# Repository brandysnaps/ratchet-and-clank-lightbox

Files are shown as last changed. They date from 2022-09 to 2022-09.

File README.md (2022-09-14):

# Ratchet & Clank Lightbox

For my brother’s 21st birthday, I wanted to combine his love of Ratchet & Clank and adding coloured lights to his room to make a custom 3D printed lightbox for his wall.

Head on over to the project [website](https://brandysnaps.github.io/ratchet-and-clank-lightbox) for more details :sparkles:

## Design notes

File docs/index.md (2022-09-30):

---
cover-img: ["assets/images/cover-img-1.jpg", "assets/images/cover-img-2.jpg", "assets/images/cover-img-3.jpg", "assets/images/cover-img-4.jpg"]
layout: home
show-avatar: false
subtitle: Building a 3D printed Ratchet & Clank lightbox for my brother's 21st birthday.
title: Ratchet & Clank Lightbox
---

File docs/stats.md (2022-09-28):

---
layout: page
title: Project stats
---

## Wakatime



### Code Time

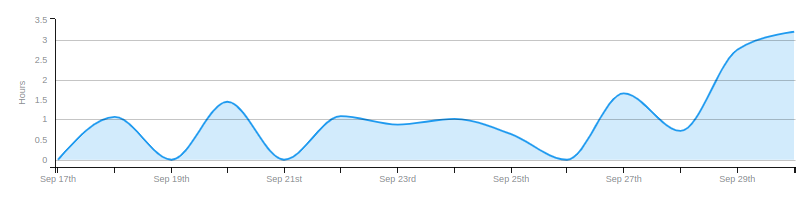
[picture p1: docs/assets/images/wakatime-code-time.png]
WakaTime code time


### Languages

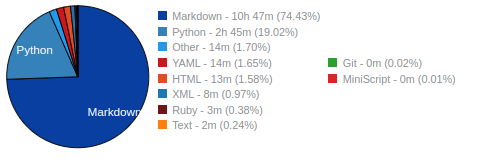
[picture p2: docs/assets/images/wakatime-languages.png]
WakaTime languages


### Files

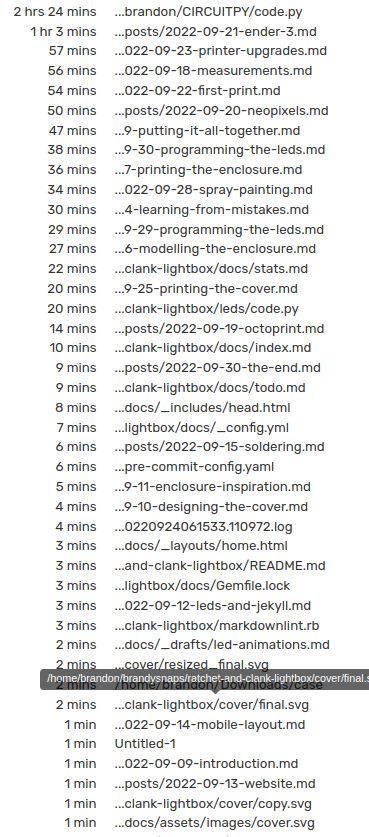
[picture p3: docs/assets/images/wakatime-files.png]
WakaTime files


## 3D Printing Time

| Print | Time (HH:mm) |
| --- | --- |
| Cover | 07:28 |
| Enclosure | 11:24 |
| Raspberry Pi Pico case | 00:39 |
| **Total** | **19:31** |

## Filament Used

| Print | Filament used (m) |
| --- | --- |
| Cover | 13.18 |
| Enclosure | 29.01 |
| Raspberry Pi Pico case | 1.36 |
| **Total** | **43.55** |

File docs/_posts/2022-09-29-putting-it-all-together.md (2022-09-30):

---
cover-img: assets/images/a-team.jpg
date: 2022-09-29 06:00:00 +1300
layout: post
readtime: true
title: "Putting it all together"
---

Now that the printed parts are dry, I have a few things to do:

* Fit test
* Soldering the connector wires to the LED strip
* Fitting the LED strip inside the enclosure
* Fitting the diffustion paper in the enclosure

## Fit Test

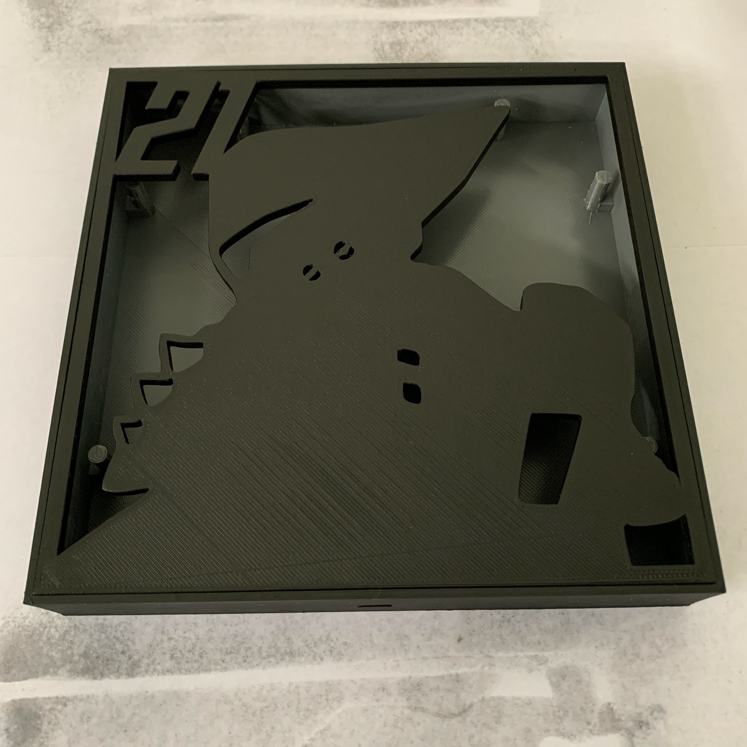
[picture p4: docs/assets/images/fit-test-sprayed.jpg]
Fit test


I am so happy with how the project is looking. The spray paint did not add any noticeable thickness to the pieces so the fit is still not that snug. Looks like I will have to use Blu-Tack or similar to hold the cover in place. That is not a big deal as long as it's not visible. Blu-Tack means the cover can be easily removed at any time to allow access to the internals.

## Soldering the Connector Wires

I soldered some female connector wires on the input end of the LED strip to allow it to easily be attached to the Pico. I soldered some male connector wires on the output end of the LED strip to allow it to easily be extended in the future:

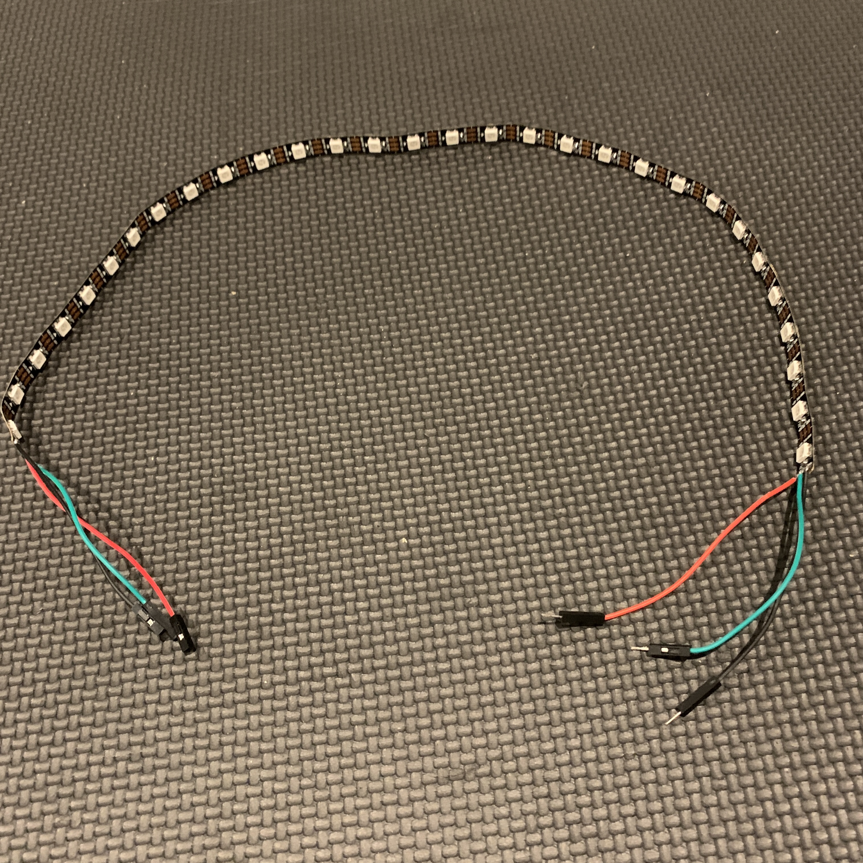
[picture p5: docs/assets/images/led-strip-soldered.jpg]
LED strip soldered


## Fitting the LED Strip

I carefully bent the LED strip at the locations of corners inside the enclosure. I did a quick fit test to make sure there were the correct number of LEDs per side and that the LED strip supports would not get in the way of the LEDs. Once I was happy, I removed the backing from strip to reveal the adhesive and stuck it to the walls of the enclosure. This is the result:

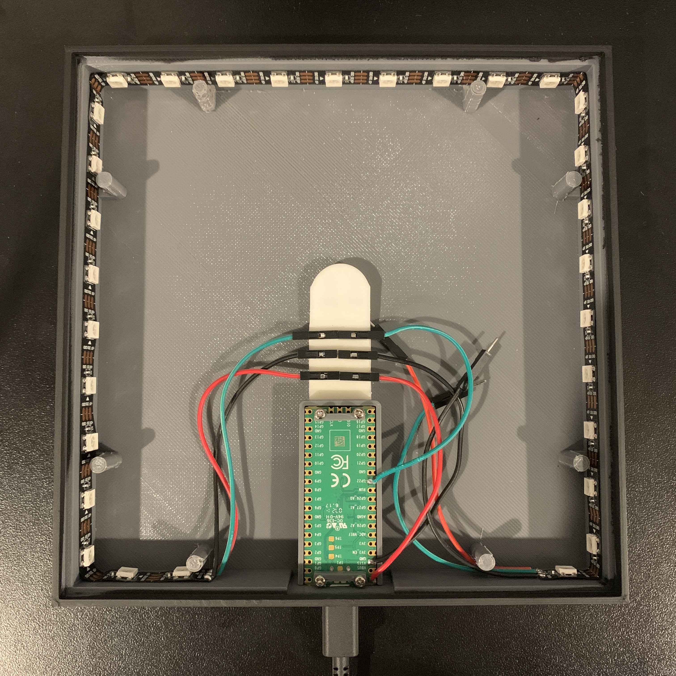
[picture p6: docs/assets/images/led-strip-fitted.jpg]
LED strip fitted


It's looking very clean if I do say so myself.

## Diffusion Paper and Cover

I cut a piece of diffusion paper (lol just joking - it's normal A4 printer paper) to size, and placed it on the inner lip of the enclosure. Next, I placed the cover on top. Are you ready for it? This is the first time everything has been put together and pretty much exactly represents the completed project:

...

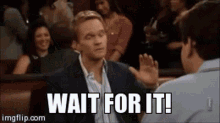
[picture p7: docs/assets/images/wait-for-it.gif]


...

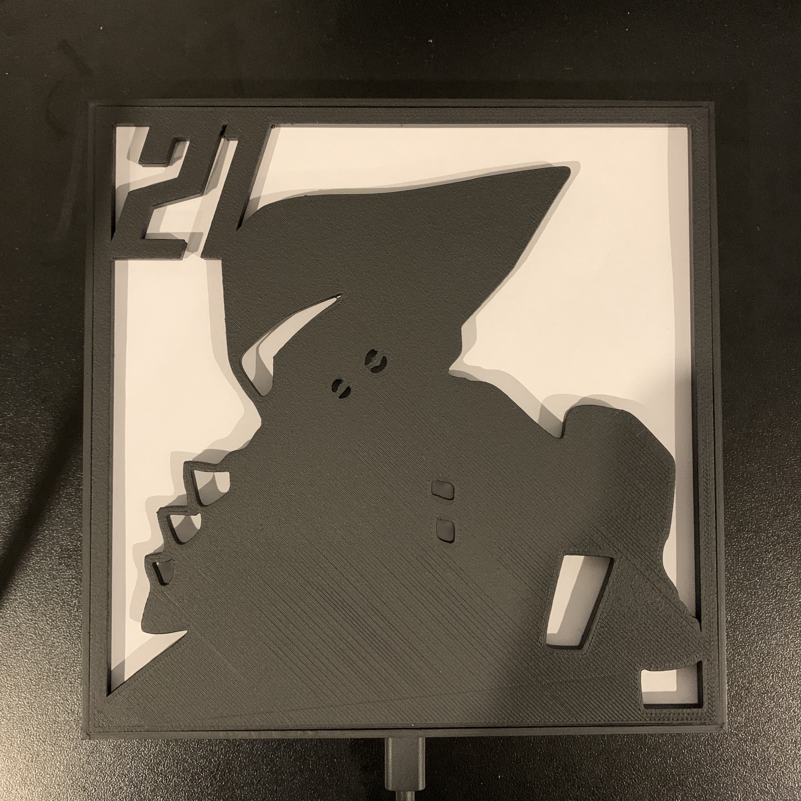
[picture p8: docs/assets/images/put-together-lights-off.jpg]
Fully assembled


Beautiful.

I wrote some basic code to get a rainbow displaying on the LED strip to see what it looks like diffusing through the paper:

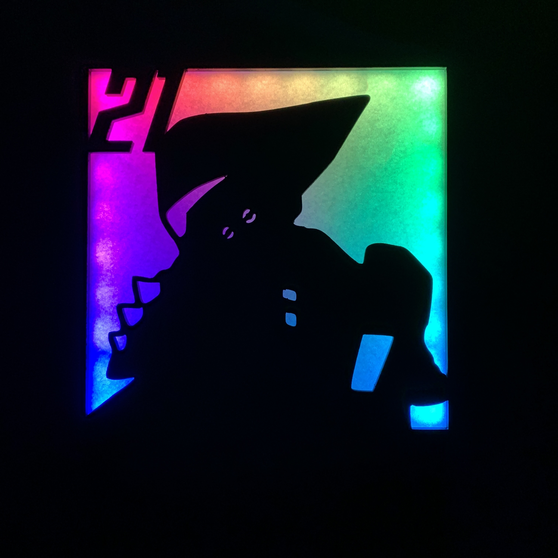
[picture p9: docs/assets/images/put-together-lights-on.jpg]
Rainbow


I'm a little disappointed with how much you can see the LEDs through the paper but there is not much I can do about that at this stage. I really need more vertical clearance between the LEDS and the paper but that would require another 3D print. I could look at printing the diffuser with some white filament in the future but don't have any on hand.

I'm sure this won't bother anyone else but I find that I tend to get critical of everything when I have been working on a project for so long 😩. Oh well, I am 93% happy.

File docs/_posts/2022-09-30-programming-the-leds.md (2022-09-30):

---
cover-img: assets/images/matrix.gif
date: 2022-09-30 06:00:00 +1300
layout: post
readtime: true
tags: [LEDs, Pico, Raspberry Pi]
title: "Programming the LED strip"
---

Now that everything is sitting where it should be, one of the last things to do is pre-program the Pico with some LED animations based on the pink and blue colour scheme my brother likes:

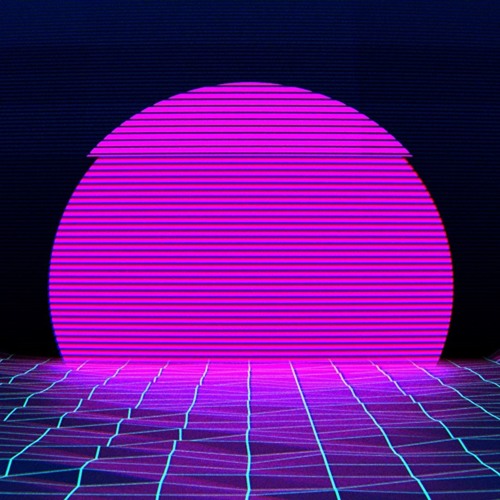
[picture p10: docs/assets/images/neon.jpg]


I am using the `adafruit_led_animation` library for the colours and animations. The first step is to include the required classes from the library, like so:

```python
import board
import neopixel
from adafruit_led_animation.sequence import AnimationSequence
from adafruit_led_animation.animation.chase import Chase
from adafruit_led_animation.animation.colorcycle import ColorCycle
from adafruit_led_animation.animation.comet import Comet
from adafruit_led_animation.animation.pulse import Pulse
from adafruit_led_animation.animation.solid import Solid
from adafruit_led_animation.animation.sparkle import Sparkle
from adafruit_led_animation.animation.SparklePulse import SparklePulse
```

The next thing to do is check is if the library provides out-of-the-box colours matching what I have in mind. I found that the `CYAN` colour from `adafruit_led_animation.color` is exactly what I want. Unfortunately, the `PINK`, `MAGENTA` and `PURPLE` colours do not match what I had in mind. Instead, I did some Googling and found a pink I liked. These are the "blue" and "pink" RGB values:

<table>
  <tr>
    <td>
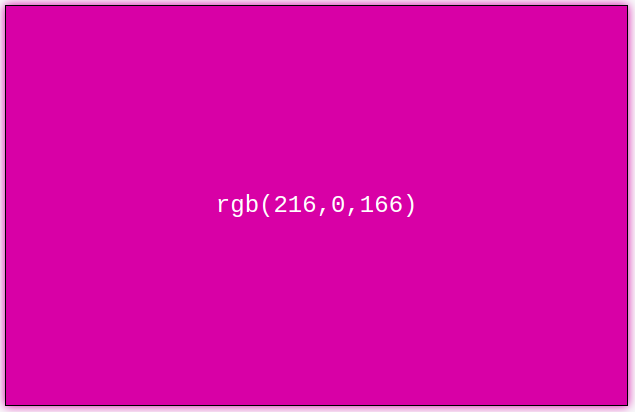
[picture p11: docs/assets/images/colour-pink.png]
      
    </td>
    <td>
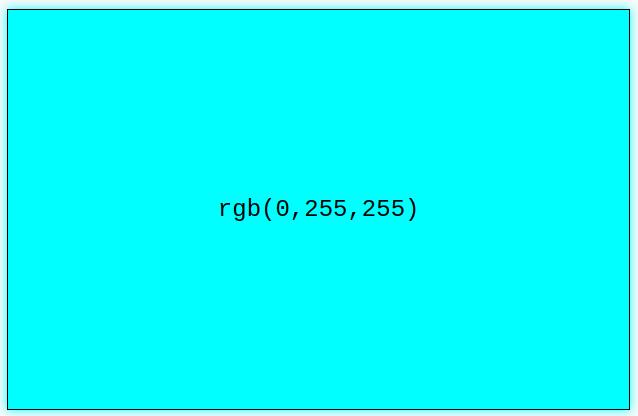
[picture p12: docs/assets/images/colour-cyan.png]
      
    </td>
  </tr>
</table>

I set up these colours in the code:

```python
from adafruit_led_animation.color import CYAN

# Define colors here
COLOR_1 = CYAN
COLOR_2 = (216, 0, 166)  # Pink
```

Next, I went through each of the animation types in the [CircuitPython LED Animations][circuitpython-led-animations] document and selected the options I thought looked the best. For example:

```python
chase_1 = Chase(pixels, speed=0.1, color=COLOR_2, size=2, spacing=3)
color_cycle = ColorCycle(pixels, speed=5.0, colors=[COLOR_1, COLOR_2])
comet_1 = Comet(pixels, speed=0.075, color=COLOR_2, bounce=False)
pulse_1 = Pulse(pixels, speed=0.1, color=COLOR_1, period=5)
```

Lastly, I had to configure an `AnimationSequence` to cycle through all of the animations I set up. I decided to let the animations be chosen at random, and for each animation to play for 60 seconds:

```python
animations = AnimationSequence(
    chase_1,
    chase_2,
    color_cycle,
    comet_1,
    comet_2,
    pulse_1,
    pulse_2,
    solid_1,
    solid_2,
    sparkle_1,
    sparkle_2,
    sparkle_pulse_1,
    sparkle_pulse_2,
    advance_interval=60,
    auto_clear=True,
    random_order=True,
)
```

Here is the complete code for reference:

```python
# Pre-programmed LED strip animations for Ratchet & Clank lightbox
#
# API documentation: https://docs.circuitpython.org/projects/led-animation/en/latest/
#
# Author: Brandon Farrell
# 29/09/2022

import board
import neopixel
from adafruit_led_animation.sequence import AnimationSequence
from adafruit_led_animation.animation.chase import Chase
from adafruit_led_animation.animation.colorcycle import ColorCycle
from adafruit_led_animation.animation.comet import Comet
from adafruit_led_animation.animation.pulse import Pulse
from adafruit_led_animation.animation.solid import Solid
from adafruit_led_animation.animation.sparkle import Sparkle
from adafruit_led_animation.animation.SparklePulse import SparklePulse
from adafruit_led_animation.color import CYAN

# Define colors here
COLOR_1 = CYAN
COLOR_2 = (216, 0, 166)  # Pink

# LED attributes
pixel_brightness = 0.5
pixel_num = 30
pixel_pin = board.GP22

pixels = neopixel.NeoPixel(
    pixel_pin, pixel_num, brightness=pixel_brightness, auto_write=False
)

# Animations
chase_1 = Chase(pixels, speed=0.1, color=COLOR_2, size=2, spacing=3)
chase_2 = Chase(pixels, speed=0.1, color=COLOR_1, size=2, spacing=3)
color_cycle = ColorCycle(pixels, speed=5.0, colors=[COLOR_1, COLOR_2])
comet_1 = Comet(pixels, speed=0.075, color=COLOR_2, bounce=False)
comet_2 = Comet(pixels, speed=0.075, color=COLOR_1, bounce=False)
pulse_1 = Pulse(pixels, speed=0.1, color=COLOR_1, period=5)
pulse_2 = Pulse(pixels, speed=0.1, color=COLOR_2, period=5)
solid_1 = Solid(pixels, color=COLOR_1)
solid_2 = Solid(pixels, color=COLOR_2)
sparkle_1 = Sparkle(pixels, speed=0.05, color=COLOR_1)
sparkle_2 = Sparkle(pixels, speed=0.05, color=COLOR_2)
sparkle_pulse_1 = SparklePulse(
    pixels, speed=0.05, period=5, min_intensity=0, max_intensity=1.0, color=COLOR_1
)
sparkle_pulse_2 = SparklePulse(
    pixels, speed=0.05, period=5, min_intensity=0, max_intensity=1.0, color=COLOR_2
)

animations = AnimationSequence(
    chase_1,
    chase_2,
    color_cycle,
    comet_1,
    comet_2,
    pulse_1,
    pulse_2,
    solid_1,
    solid_2,
    sparkle_1,
    sparkle_2,
    sparkle_pulse_1,
    sparkle_pulse_2,
    advance_interval=60,
    auto_clear=True,
    random_order=True,
)

while True:
    animations.animate()

```

Once the complete code had been successfully uploaded to the Pico, I disconnected it and started packaging it in the box I will give my brother...

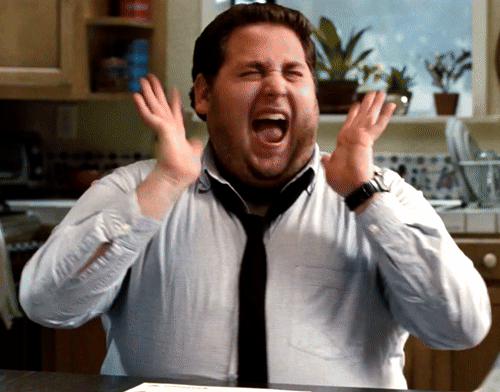
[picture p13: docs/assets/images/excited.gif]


## QR Code

It's a small thing but excited me nonetheless. I created a QR code linking to the website. I will make the site live tonight.

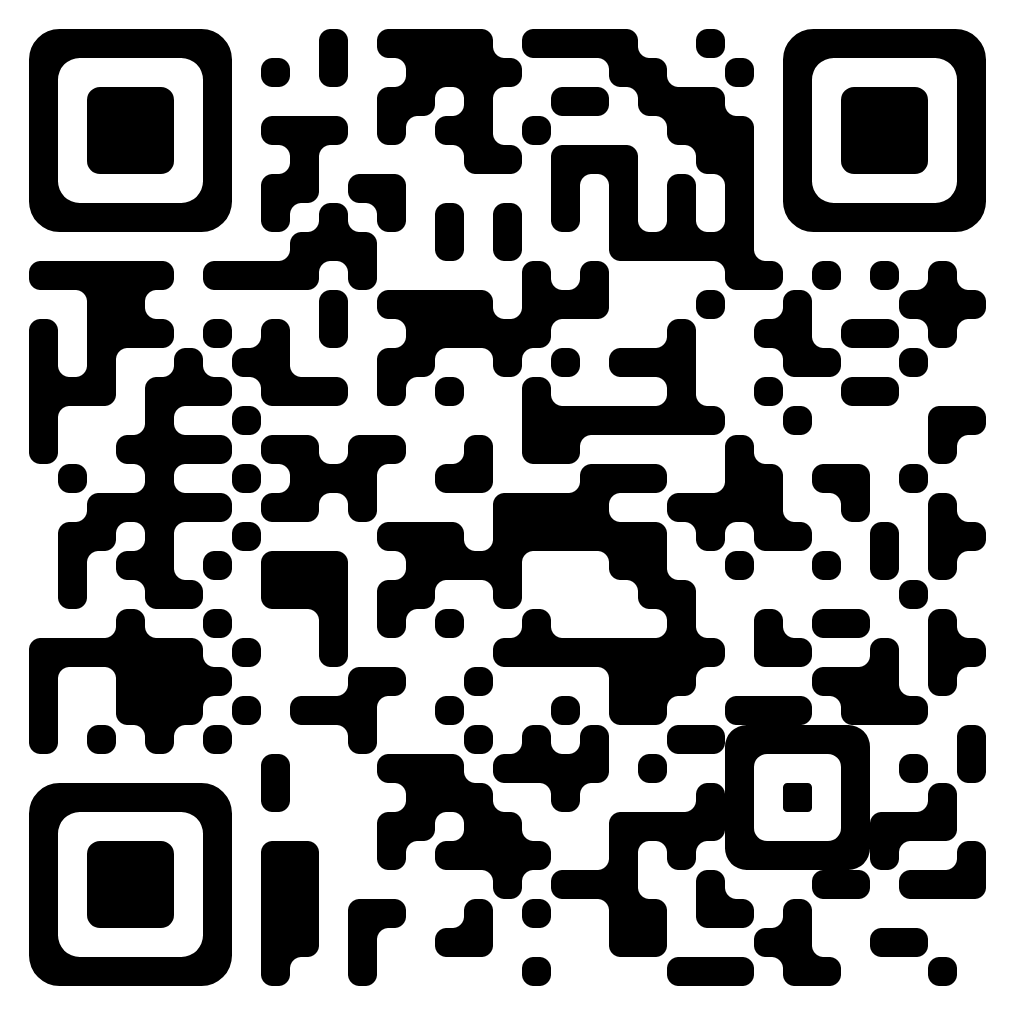
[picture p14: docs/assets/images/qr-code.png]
QR code


[circuitpython-led-animations]: https://learn.adafruit.com/circuitpython-led-animations

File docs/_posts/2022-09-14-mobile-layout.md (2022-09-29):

---
cover-img: assets/images/micropython-pico.jpg
thumbnail-img: assets/images/micropython-pico-thumbnail.jpg
date: 2022-09-14 06:00:00 +1200
layout: post
readtime: true
tags: [Raspberry Pi, Pico]
title: "Mobile layout & Raspberry Pi Pico"
---

I started today by trying to tackle the small mobile layout issues I found last night. In the evening, I started reading about getting my Raspberry Pi Pico set up.

## Mobile Layout Issues

Having a look at the mobile layout for the website reveals a couple of issues:

Mobile issues

Firstly, the main site heading is covered by the centered avatar. There is also a random navigation button up the top right that has nothing in it.

I decided to shorten the main site title to `R&C Lightbox` as there are other references to the full name elsewhere. That addresses the first issue but unfortunately I was not able to find a fast and good solution to the second problem. My options would be to update the beautiful-jekyll theme with custom logic for mobile, or create an issue on the project itself asking the author to fix it. I am short on time so will leave it as is for now. If I do end up adding any other page types to the site, this will not be an issue as the navigation button will no longer be empty.

## Raspberry Pi Pico

For a long time, I have wanted to make my way through the [Get Started with MicroPython on Raspberry Pi Pico book from Hackspace][micropython-pico]:

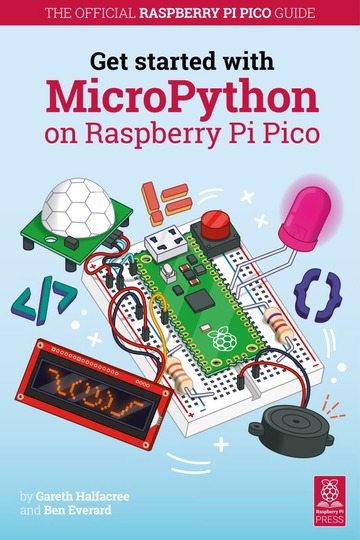
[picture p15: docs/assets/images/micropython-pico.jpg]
Get Started with MicroPython on Raspberry Pi Pico book


Like a few other things I have wanted to do for a long time, this project has given me the motivation to finally start.

I read about the different parts of the Pico and how to solder the header pins to it safely. This is what I will do first.

[micropython-pico]: https://hackspace.raspberrypi.com/books/micropython-pico

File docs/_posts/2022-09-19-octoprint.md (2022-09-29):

---
cover-img: assets/images/octoprint.png
date: 2022-09-19 06:00:00 +1200
layout: post
readtime: true
tags: [3D printing, Octoprint]
thumbnail-img: "assets/images/octoprint-thumbnail.png"
title: Octoprint
---

I spent a little time today getting [Octoprint][octoprint] installed and running on an old Raspberry Pi model B I had lying around. Octoprint will let me monitor the printing process remotely and create timelapses of any prints I make. I would like to include a timelapse of printing this project as I think it would be a nice touch.

The camera module I have was suprisinly easy to set up. I will have to figure out how to mount the camera to properly view the print bed, but that will come later (once I've actually built the printer 🤦‍♂️).

The one concern I have it that my Rasperry Pi model B is old and may struggle to run Octoprint. The website recommends model 3 onwards.

[octoprint]: https://octoprint.org/

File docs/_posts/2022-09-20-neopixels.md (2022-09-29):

---
cover-img: "assets/images/neopixels.gif"
date: 2022-09-20 06:00:00 +1200
layout: post
readtime: true
tags: [LEDs, Raspberry Pi, Pico]
title: "NeoPixels"
---

My goal for today is to be able to control a strip of NeoPixel LEDs using the Raspberry Pi Pico.

I found the [NeoPixel LEDs][adafruit] post on Adafruit's website that seems to be exactly what I want to do.

The first thing I did was cut my LED strip to the correct size (30 LEDs) and grabbed some wires to let me control the strip to the header pins on the Pico.

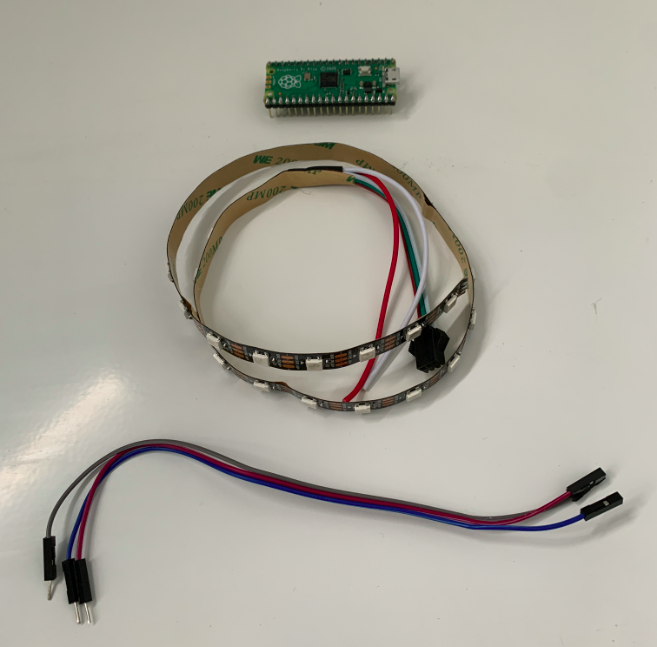
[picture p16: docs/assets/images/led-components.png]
Components


## Wiring the NeoPixel LED Strip

I wired everything up as follows:

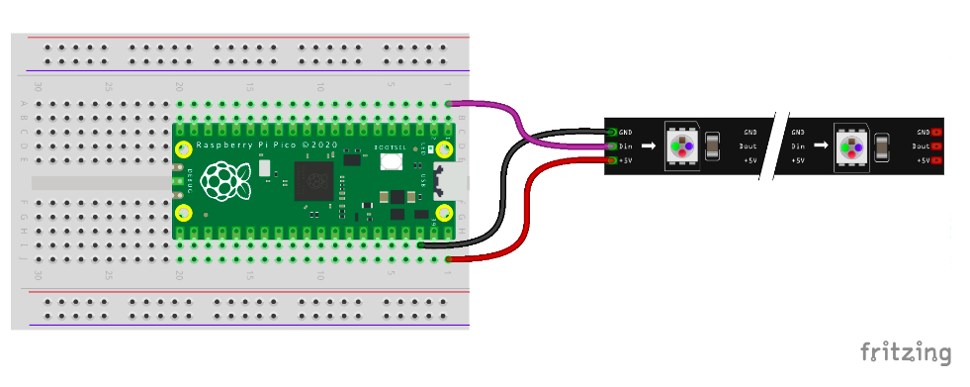
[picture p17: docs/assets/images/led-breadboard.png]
Wiring diagram


## Installing the Adafruit CircuitPython NeoPixel Library

Once that was done, I downloaded CircuitPython for the Pico. This was a UF2 file. I held down the **BOOTSEL** button on the Pico before plugging it into my laptop. This brought it up as a drive labelled `RPI-RP2`. I dragged the UF2 file to the new drive. After a couple of seconds, it reappeared with the name `CIRCUITPY`. Apparently this means CircuitPython is successfully installed 🎉.

The next step was to download the necessary library to use the NeoPixels. I copied the `neopixel.mpy` file to the `lib` directory as instructed by the docs. I then replaced the contents of the `code.py` file with the following:

```python
# SPDX-FileCopyrightText: 2021 Kattni Rembor for Adafruit Industries
#
# SPDX-License-Identifier: MIT

"""
NeoPixel example for Pico. Turns the NeoPixels red.

REQUIRED HARDWARE:
* RGB NeoPixel LEDs connected to pin GP0.
"""
import board
import neopixel

# Update this to match the number of NeoPixel LEDs connected to your board.
num_pixels = 30

pixels = neopixel.NeoPixel(board.GP0, num_pixels)
pixels.brightness = 0.5

while True:
    pixels.fill((255, 0, 0))
```

I wasn't really expecting anything to happen but after saving the file, to my surprise:

My eyes!

Even at 50%, these things are bright.

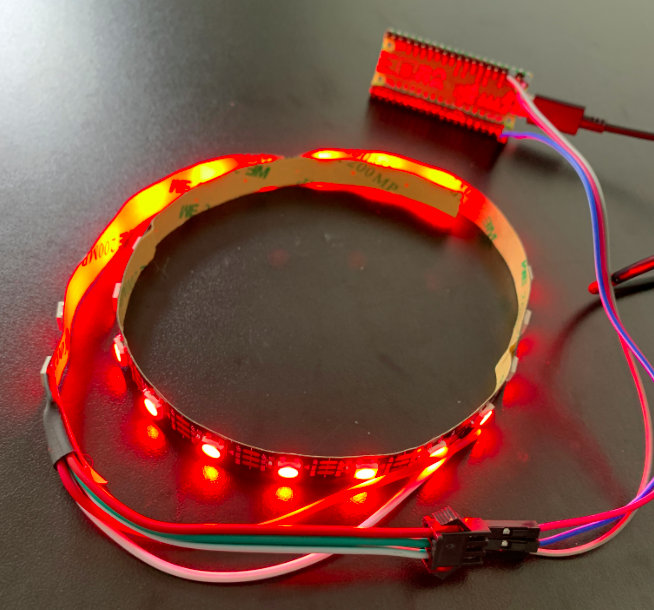
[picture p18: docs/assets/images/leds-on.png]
Let there be light


Reference: [Adafruit CircuitPython NeoPixel][circuit-python-neopixel]

## Animations

The next thing I want to look at is creating some animations based around the blue and pink colour scheme my brother likes.

This looks like a good place to start: [CircuitPython LED Animations][animations]

[adafruit]: https://learn.adafruit.com/getting-started-with-raspberry-pi-pico-circuitpython/neopixel-leds
[circuit-python-neopixel]: https://github.com/adafruit/Adafruit_CircuitPython_NeoPixel
[animations]: https://learn.adafruit.com/circuitpython-led-animations

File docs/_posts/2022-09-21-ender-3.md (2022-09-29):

---
cover-img: assets/images/desk.jpg
date: 2022-09-21 06:00:00 +1200
layout: post
readtime: true
thumbnail-img: "assets/images/ender-3-thumbnail.jpg"
tags: [3D printing]
title: "Building the Ender 3"
---

I have been both looking forward to and dreading this day for a long time. I bought the Creality Ender 3 3D printer about 6 months ago but have still not built it. Life got busy and I was convinced something would go wrong, so I lost the motivation I had before to buy and build my own printer.

But... I cannot give my brother a 3D printed lightbox without having a functioning 3D printer 😅.

So here it goes...

I open the box the printer comes in to see what I am dealing with. First glance makes me feel like this won't be so bad:

Box contents

I started unpacking and surprise! There is another layer:

Box contents (part 2)

...

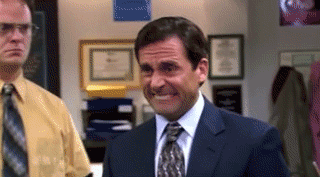
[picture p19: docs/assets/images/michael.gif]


I unpacked everything and laied it on the ground to get a better idea of what I was dealing with:

Printer components

I should have really unpacked those bags on the left because there were many, many parts in there. Following the single-page instruction manual was not too difficult and I supplemented that with a YouTube video. After about an hour, I ended up here:

Partly built

This is apparently the most important part to get right and makes up the core of the printer. If the vertical and horizontal members are all square and secure, the printer should print with decent results.

After a couple more hours, and a long break in the middle (who has spare time with young kids running around? 😂), it was done:

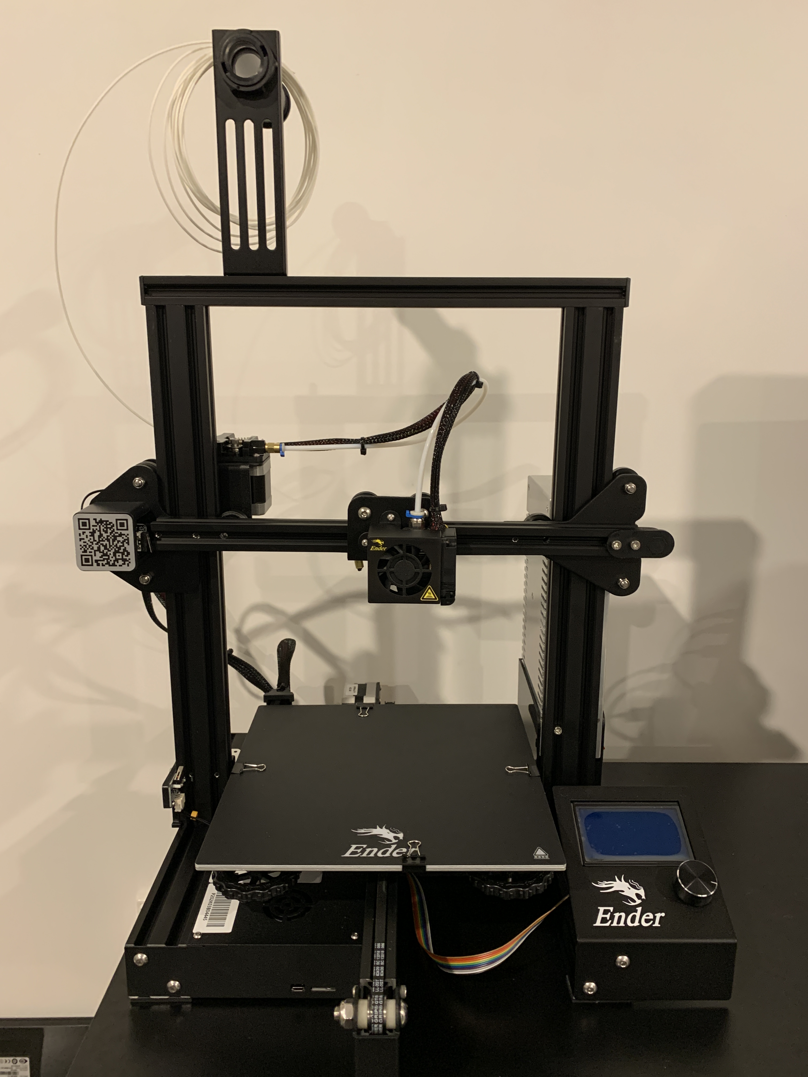
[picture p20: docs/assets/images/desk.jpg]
Finished printer


I really wanted to include a video here but I will have to figure out how to do that later. Here is my first print!

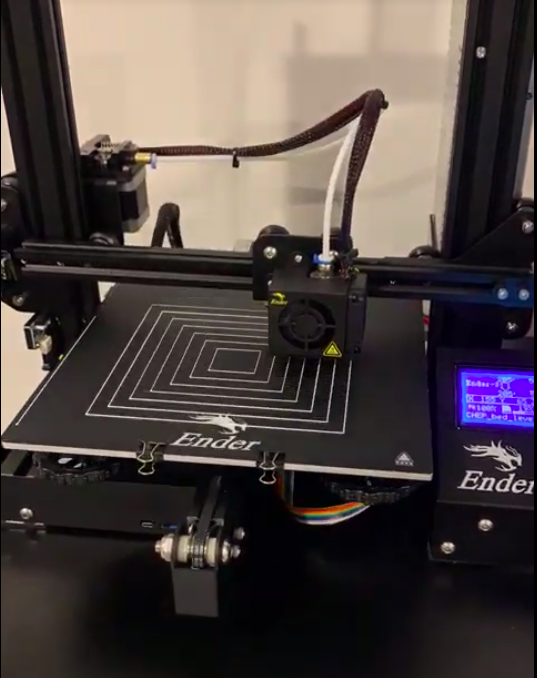
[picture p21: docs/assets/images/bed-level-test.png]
Bed level test


This was a simple bed level test, to make sure I had the print bed nice and level relative to the nozzle.

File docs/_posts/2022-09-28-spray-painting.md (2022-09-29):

---
cover-img: assets/images/spiderman-spray-paint.jpg
date: 2022-09-28 06:00:00 +1200
layout: post
readtime: true
title: "Spray painting"
---

I was happy with the spray paint test I did the other day but obviously when it comes to doing the real thing, the pressure is on!

From what I have read about post-processing 3D prints, it is a good idea to suspend the print in the air from a piece of string or similar. You then apply even strokes of paint while rotating the print. I used some thin string and tied it to the cover and enclosure.

The spray paint I am using is Flat Black Rust-oleum:

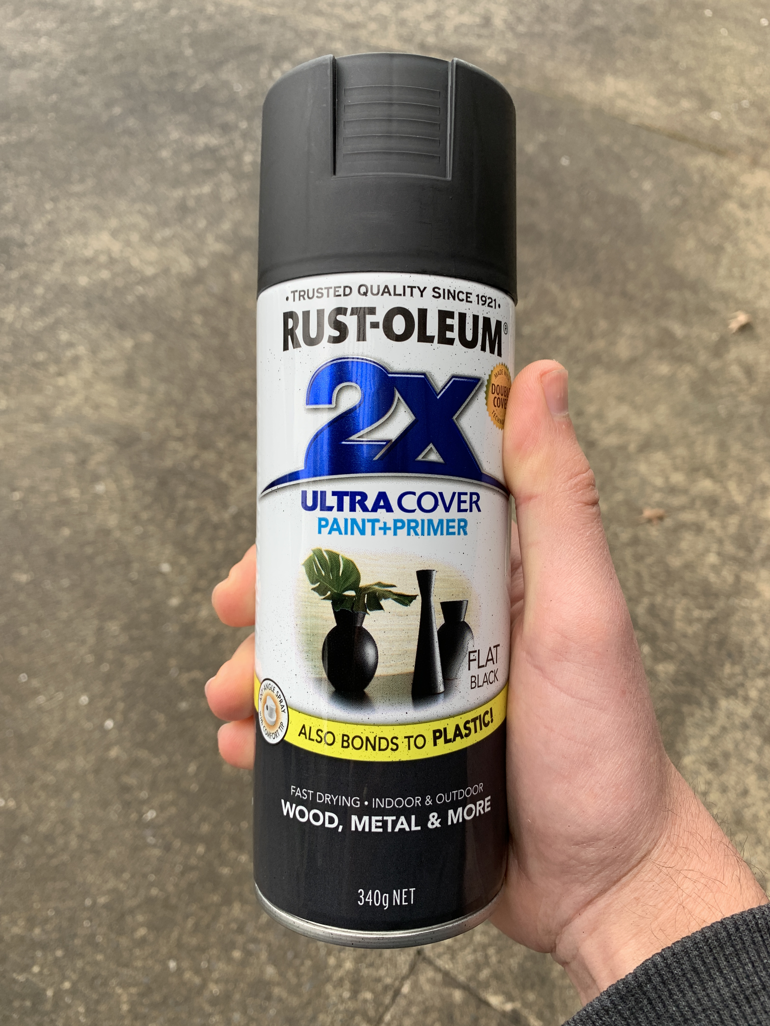
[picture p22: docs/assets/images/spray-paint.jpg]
Rust-oleum


I started with the enclosure and tried to apply nice even strokes. I could tell pretty quickly that hanging the piece vertically was not the best idea. A drip-like pattern was appearing on the back of the enclosure as gravity caused the paint to move. From then on, I decided to just lay the pieces flat and spray on top of some paper. When dry, I would turn the piece over and spray the other side. I did two coats of paint per side:

Cover sprayed

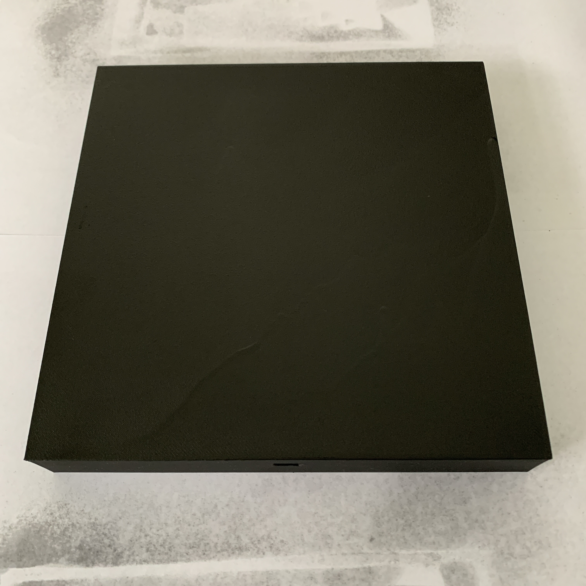
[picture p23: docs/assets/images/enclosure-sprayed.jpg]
Enclosure sprayed


I will leave both pieces to dry for 24 hours before trying to fit them together.

## Soldering the Wires to the Pico

I initially wanted to avoid soldering anything to the Pico itself because that is semi-permanent. My preference was to use wires with female headers on one end and plug them into the header pins on the Pico. Unfortunately, that increases the height of the Pico a lot, and I would have to make the enclosure a lot thicker to accommodate for this. My goal was to make the project as thin as possible so I decided to solder the three required wires directly to the Pico. As you can see, this adds no height and is far easier to fit into a thin space:

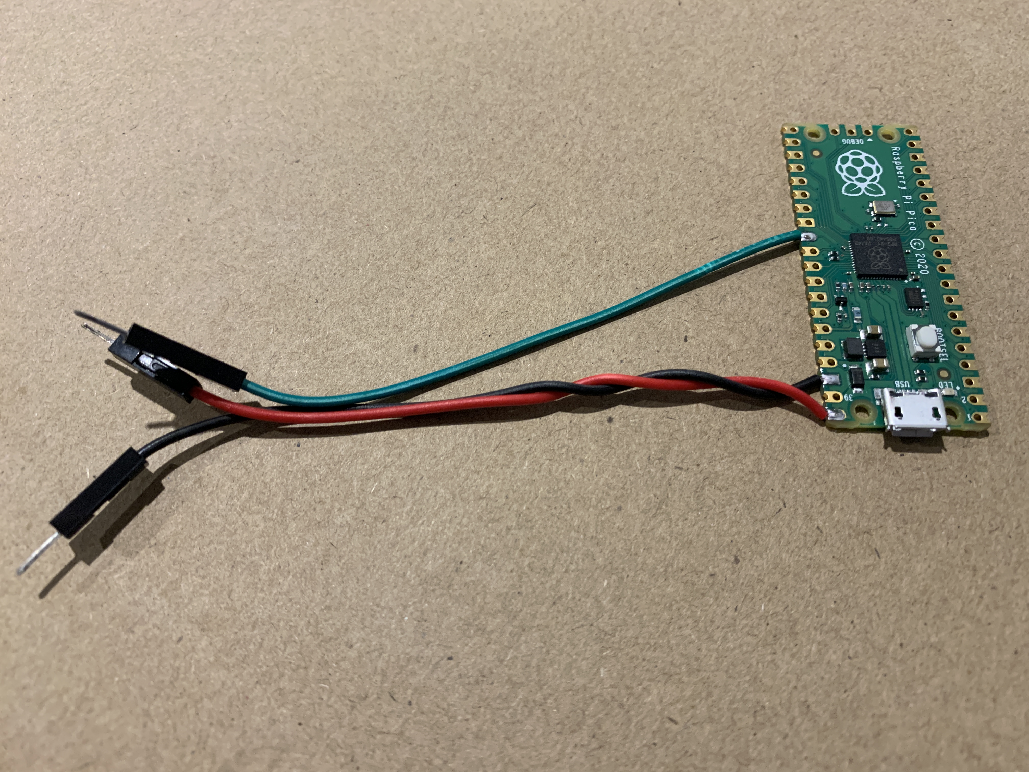
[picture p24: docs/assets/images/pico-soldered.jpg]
Pico with wires soldered


The data wire (green) was originally set to the bottom right pin shown in the picture above (GP0):

{% highlight python %}
pixels = neopixel.NeoPixel(board.GP0, num_pixels, auto_write=False)
{% endhighlight %}

If I kept using the bottom right pin, I would have had to bend it over/under the Pico to be on the same side as the red (VBUS) and black (GND) wires. Instead, I decided to use a GPIO pin on the left side of the board, as close to the other wires as possible. GP22 seemed like a good candidate so I changed the wiring and updated the code to the following:

{% highlight python %}
pixels = neopixel.NeoPixel(board.GP22, num_pixels, auto_write=False)
{% endhighlight %}

The LED strip turned on as expected 💡.

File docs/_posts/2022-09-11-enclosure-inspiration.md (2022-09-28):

---
cover-img: assets/images/lightbox-inspiration.jpg
date: 2022-09-11 00:00:00 +1200
layout: post
readtime: true
tags: [3D printing, Tinkercad]
title: "Initial thoughts on the enclosure"
---
Today was all about getting a better idea of what the enclosure will look like. I have an idea of what I want it to look like in my head but when it comes to putting that into millimeter measurements, that's a bit more challenging.

I've decided to go with a 200 mm x 200 mm square. I think 30 mm think will work but I won't know until I am actually holding something in my hand.

Dimensions

One of the other things that is bothering me is how I am going to attach the image to the rest of the encolsure. Possible options include glue, bolts and friction. I want something that is not permanent so my brother can switch out the front picture if he wants. This pretty much rules out glue. I have the least confience in friction because it relies on 3D printing with very small tolerances so the pieces fit together nicely. Bolts seemed to be the best option but I don't know how to make this work without losing some space on the image for bolt holes.

Image mounting options

The next challenge is how to mount the Raspberry Pi Pico inside the enclosre. One of the features I've decided on is to be able to plug a power cable directly into the enclosure so the Pico needs to be mounted in such a way that it's power port is accessible and does not move when something is plugged into it.

This is what I have in mind to start with:

<table>
  <tr>
    <td>
      Not found
    </td>
    <td>
      Not found
    </td>
  </tr>
</table>

It also needs to be easily removable and detachable from the electronic wiring so it can have new software flashed to it.

I stumbled onto some nice case designs for a Pico that I think I can adapt to work well:

| **Upper case** | Upper case
| --- | --- |
| **Lower case** |Lower case|

Reference:[Slim modular Raspberry Pi Pico Case][pico-cases]

The idea is keep the mounting holes in place but stretch the **Upper case** design to the dimensions I want (200 mm x 200 mm). This should leave me with mounting holes for a Pico at one of the edges with the power port easily accessible.

The Pico is then sandwiched between the upper and lower cases to hold it in place with some bolts.

This is what the case looks like with a Pico inserted and no modifications:

Pico

[pico-cases]: https://www.thingiverse.com/thing:4808999

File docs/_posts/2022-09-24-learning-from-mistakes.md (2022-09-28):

---
cover-img: "assets/images/this-is-fine.jpg"
date: 2022-09-24 06:00:00 +1200
layout: post
readtime: true
tags: [3D printing, Octoprint, Cura]
title: "What have I gotten myself into?"
---

They say that you learn from your mistakes. I learned a lot today.

I wanted to print this cable chain to tidy up the wiring at the back of the printer:

Cable chain

There are a couple of models in this [Thingiverse][thingiverse] thing that need many copies of it printed. I thought it would be a good idea to print as many of them in a single print batch as possible, so I do not have to set up the same print 19 times. I imported the model into Cura and used the multiply function to get the required number of pieces:

Cura layout

This looked great so I started the print and went on my merry way. The print was supposed to take around 9 hours. I checked back in after around an hour and already suspected something was wrong. The quality on each of the pieces just wasn't what I expected it to be.

After around 5 hours, things were looking very bad. Some of the pieces were very messy and looked like they had clouds of fine spaghetti plastic on their top. I decided to cancel the print. The pieces would not have been usable and I didn't want to waste even more filament.

I thought about this for a while and realised what the likely problem is. The printer was printing a single layer at a time for all pieces on the print bed. It would print a layer for the first piece, then a layer for the second, and so on. Once all pieces had their first layer printed, it would return to do the second layer on the first piece. The print head was moving so much between all the pieces, leading to the stringing I was seeing. I wonderered if there was a way to print each piece in its entirety before moving on to the next one. I would still be printing one piece at a time but would not need to do all the set up if I were printing a single piece on the print bed at a time.

Turns out there is a setting in Cura for that: Special Modes -> Print Sequence -> One at a Time.

The "downside" with that setting is that you cannot print as many models on the bed, because the print head needs enough clearance when moving between pieces so nothing gets bumped around. I found that I was able to fit 6 of the smaller model on the bed at a time.

I kicked off the next print and immediately saw a problem. For some reason, the first layer was a complete mess. The extruder did not seem to working properly at all. Basically, it looked like the printer stopped working altogether...



Took me a while to figure out the cause of this one. I noticed an issue at the top of the stepper motor that feeds filament into the bowden tube. There were specs of filament on it and the filament itself had notches taken out of it from the teeth on the stepper motor. This was almost certainly caused by all of the extrusion and retraction of the filament from the disaster of the previous print. I checked the 'Maximum Retraction Count' setting in Cura and it was set to 100. That is WAY too high and it's no surprise I wrecked the filament. I reduced that setting to 5, started a new print and things were back to normal.

I need a drink

The plan for tomorrow is to print the cover of my brother's present. Hopefully it's a more successful day...

[thingiverse]: https://www.thingiverse.com/thing:3769941

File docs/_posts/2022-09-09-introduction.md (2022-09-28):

---
cover-img: assets/images/introduction.jpg
date: 2022-09-09 00:00:00 +1200
layout: post
readtime: true
title: "Introduction"
---
For my brother's 21st birthday, I wanted to combine his love of Ratchet & Clank and adding coloured lights to his room to make a custom lightbox for his wall.

He is a big fan of this pink and blue neon style:



He was recently showing me something on his computer and I spotted a profile picture he had made for himself:

Profile picture

My goal is to build a physical representation of this profile picture using a 3D printer, Rasperry Pi Pico and some RGB LEDs.

I found this on Thingiverse with has a similar feel for what I want to create:

Hexaleafs

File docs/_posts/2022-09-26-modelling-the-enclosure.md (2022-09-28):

---
cover-img: assets/images/enclosure-top-right.png
date: 2022-09-26 06:00:00 +1200
layout: post
readtime: true
tags: [3D printing, Cura, Pico, Raspberry Pi, Tinkercad]
title: "Enclosure modelling & spray paint test"
---

It took me a long time to get something I was happy with:

Enclosure model (top-right)
Enclosure model (top)

I imported the STL of the cover to make sure everything fits. It would be a disaster to print the enclosure, only to discover my measurements were wrong.

Enclosure with cover (top-right)
Enclosure with cover (top)

I decided to keep the case for the Pico separate from the enclosure so that it can be swapped out for the ESP32 development board which is currently on its way from China. The reason I want to use the ESP32 is so that the LED strip can be controlled with [WLED][wled]. WLED offers the following advantages:

* Over 100 special effects
* Mobile app for remote control
* Alexa voice control (including dimming and color)
* Nightlight function (gradually dims down)

Unfortunately, I cannot do this with the non-wireless Pico I have so he will have to make do with my pre-programmed lighting animations for now 😂.

The plan is to use a couple 3M Velcro strips to hold the Pico (and later ESP32) board in place. It should be strong enough to allow plugging the power cable in from the outside without it moving around.

I did a quick slice of the STL file to get an idea of the print time. More than 17 hours… oh my. I referred back to the [Hexaleaf Thingiverse][hexaleaf] page and saw the author printed at a layer height of 0.2 mm. I did the cover at 0.12 mm and was very happy with the quality. However, re-slicing in Cura with a layer height of 0.2 mm means a print time of just over 12 hours. This seems more reasonable so is what I have decided to go with:

Enclosure sliced

## Spray Paint Test

I grabbed a piece of orange scrap from one of my previous failed prints. I used orange because I figure if black spray paint can hide orange, it can certainly hide grey. I hung the piece up outside, gave the can a good shake and tried to do nice even strokes with the spray until I had completely covered the face. I left it to dry for around an hour before taking it inside to look at the results. I am blown away with the difference! Not just the colour but the finish to the surface as well.

There was nothing wrong per se with the finish before but you could clearly see the print lines:

Unsprayed scrap

Compared to the sprayed black side, the surface is clearly smoother and has a nice matte finish:

Sprayed scrap

I feel more confident taking the spray can to the cover now as long as I use the same technique as the test piece.

## Raspberry Pi Pico Case

I printed the case for the Raspberry Pi Pico that will sit inside the enclosure. I am happy with the result and glad to see the M2 8 mm screws I have work 😅. It is the first time I have really relied on the accuracy of my printer. If the screw holes were not printed at the correct size, the screws would not have worked.

Raspberry Pi Pico case

Tomorrow I will be printing the enclosure…

[hexaleaf]: https://www.thingiverse.com/thing:5154193
[wled]: https://kno.wled.ge/

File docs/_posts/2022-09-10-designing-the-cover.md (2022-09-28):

---
cover-img: assets/images/final_svg.png
date: 2022-09-10 00:00:00 +1200
layout: post
readtime: true
tags: [Gimp, Inkscape]
title: "Designing the cover"
---
The first task in my mind was to get the front image of the lightbox designed. From what I have read, the best way to get a clean image for 3D printing is to create a SVG formatted file that I can import into it Tinkercad to generate a STL file that the 3D printer can use.

This is the image I am taking inspiration from:

Profile picture

I want to be able to shine light through all of areas my brother has highlighted in pink, as well as the background behind Rathet.

After spending some on Google, I was able to find the original image. I wanted to make sure the orientation and details matched as closely to the above image as possible:

Original image

From here, I used Gimp to make the original set of image modifications.

## Gimp

### Crop

The first step was to crop the image and remove the background colour:

Sized image

### Highlight Details

I then highlighted the key areas I want light to come through:

Accents image

I decided to highlight the rings on Ratchet's mask as well to give the light somewhere else to come through. All of the detail of his suit will be lost in the final product so I want it to have as much detail as possible. It's a slight deviation from my bother's profile picture but hopefully he won't mind 😅.

### Add Outline

I want the spikes on Ratchet's shoulder to be illuminated, as well as the entire background. I needed to make sure there was a solid outline between the two so you can see the detail of the spikes:

Outlined image

## Remove Other Details

The last step was to end up with an image showing only the areas I want the light to come through:

Final image

This is a basic representation of what I hope the lightbox will look like. The green areas are where light will come through, the back is what will be 3D printed.

## Inkscape

The edges on the JPEG image above are not very clean and if I want to scale this image up, it will get blurry. I read about using a feature in Inkscape called "Bitmap tracing" to convert an image to the SVG format. SVG is a vector-based format at retains it's detail, no matter the scaling.

I wanted to add a border and "21" to the final image. This is what I ended up with:

Final SVG

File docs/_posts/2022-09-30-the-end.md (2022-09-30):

---
cover-img: assets/images/the-end.jpg
date: 2022-09-30 20:00:00 +1300
layout: post
readtime: true
title: "The end"
---

Well, there you have it. After 20 hours making this website, 20 hours printing and countless more hours thinking, designing and making, I have reached the end of the project. It's been a whirlwind trying to get this ready 😅.

Everything is packaged and now ready to present to my brother:

Packed box
Packed box

## To my brother

Happy 21st birthday! I cannot believe you have reached this milestone already. You are hands down, one of the best people I have the privilege of knowing and it's been such a joy watching you grow. I will forever cherish the memories I have of us bonding over Ratchet & Clank.

I hope this lightbox makes a fitting addition to your room. Given everything I have learned working on this project, if you want anything tweaked, let me know 😁.

Love you lots,

Brands

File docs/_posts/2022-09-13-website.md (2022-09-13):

---
# cover-img: "assets/images/website.png"
date: 2022-09-13 21:00:00 +1200
layout: post
readtime: true
tags: [Jekyll, Wacom]
thumbnail-img: "assets/images/website_thumbnail.png"
title: "Shiny new website!"
---
I spent WAY too much time today working on this website. I tend to do this. Going down rabbit holes of things that interest me rather than working on the highest priority task 😅.

## Beautiful Jekyll

Anyway, I found the [beautiful-jekyll][beautiful-jekyll] Jekyll theme and was inspired to use it for this site.

It's so beautiful

After figuring out how to make it work both locally and on GitHub, I went through the documentation to configure things just right.

I noticed right before going to bed that the mobile layout for the site is not rendering as I expected. Need to look into this tomorrow.

## Drawing Tablet

I have been wondering how to get the physical sketches I have of this project into this site. I considered just taking photos of everything, but I don't think these would look very nice considering a lot of them are just tiny pencil sketches on random bits of paper.

My brother recently bought himself a relatively cheap Wacom drawing tablet which he seems happy with. I did some research on the [One by Wacom][one-by-wacom] drawing tablet and it looks like it will work well for what I want to do. My brother confirmed this is the one he has too! It was fun asking him about it, knowing he has no idea what my plans are for his birthday 😁.

So, I took the plunge and am now the proud owner of one of these:

One by Wacom

## Sketchpad

I did some very quick digging and I should be able to use [Sketchpad][sketchpad] for creating all of my sketches.

[beautiful-jekyll]: https://github.com/daattali/beautiful-jekyll
[one-by-wacom]: https://estore.wacom.com/en-NZ/catalog/category/view/s/tablets/id/45/#one-by-wacom
[sketchpad]: https://sketch.io/sketchpad/

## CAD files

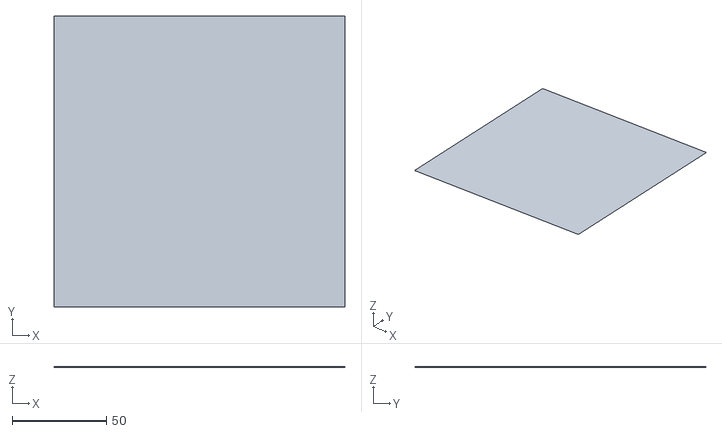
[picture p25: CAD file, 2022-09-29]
3d-printing/diffuser.stl
154.0 x 154.0 x 0.4

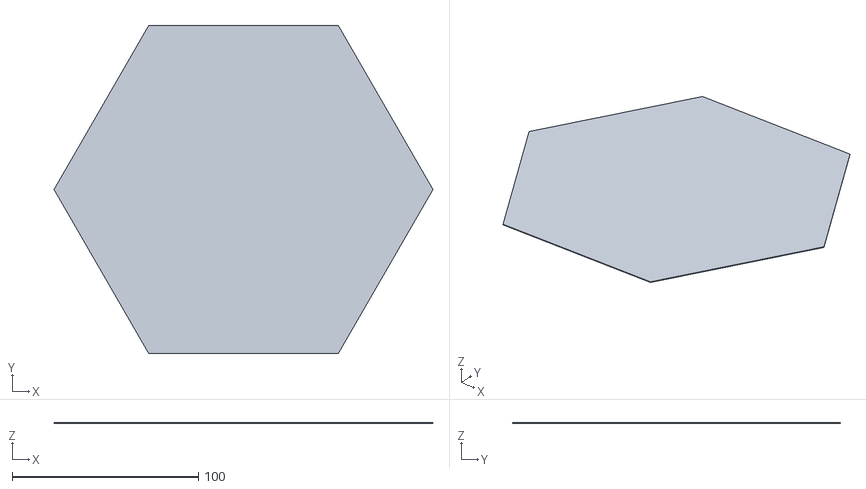
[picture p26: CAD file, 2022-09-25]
3d-printing/reference-models/Hexaleaf/Hexaleaf_Diffuser.stl
203.2 x 176.0 x 0.4

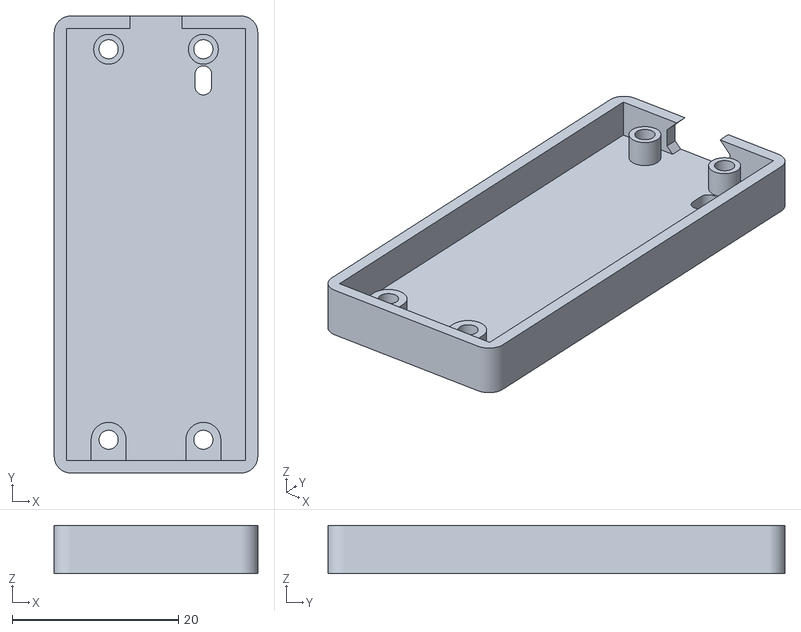
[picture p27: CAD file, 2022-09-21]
3d-printing/reference-models/Slim modular Raspberry Pi Pico Case/Case_Upper_No_Text.STL
24.5 x 55.0 x 5.80

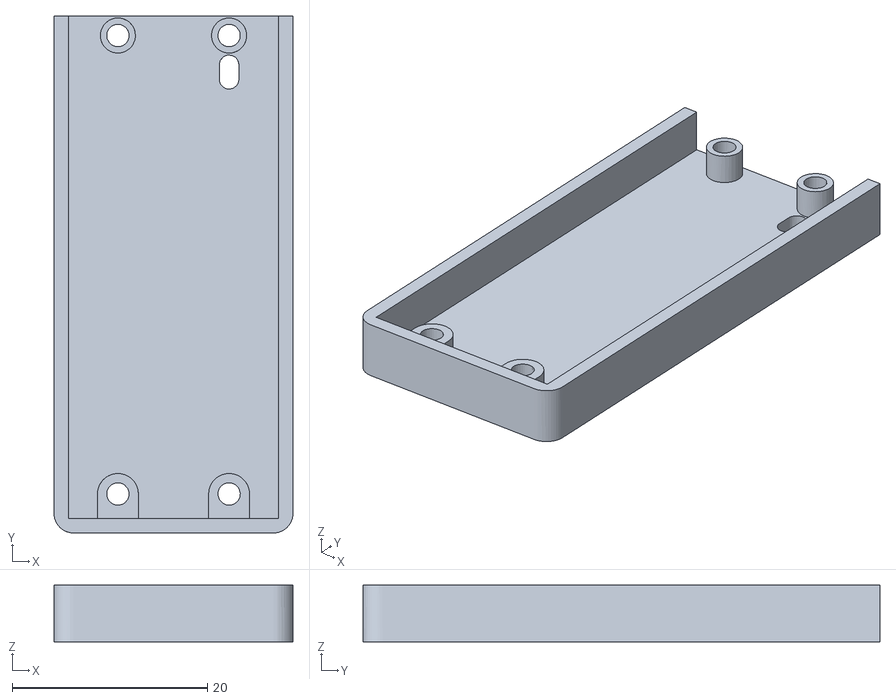
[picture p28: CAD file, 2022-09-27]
3d-printing/pico-case.stl
24.5 x 53.0 x 5.80

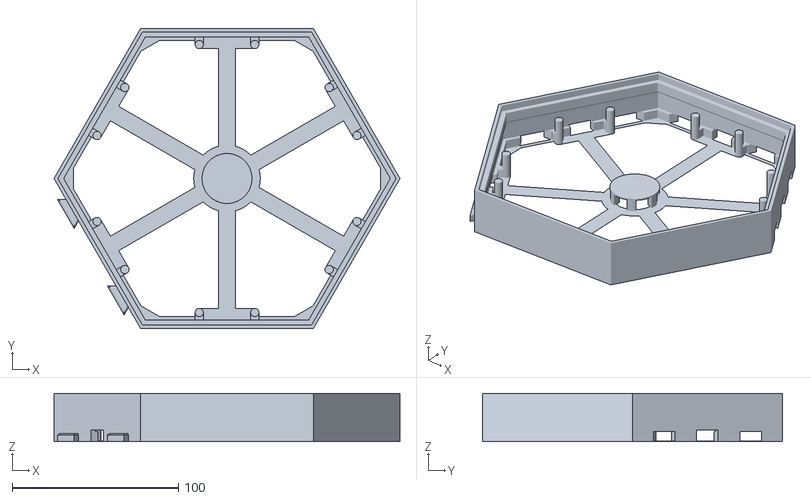
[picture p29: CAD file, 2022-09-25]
3d-printing/reference-models/Hexaleaf/IP65_Hexaleaf_m00fff.stl
207.8 x 180.0 x 29.0

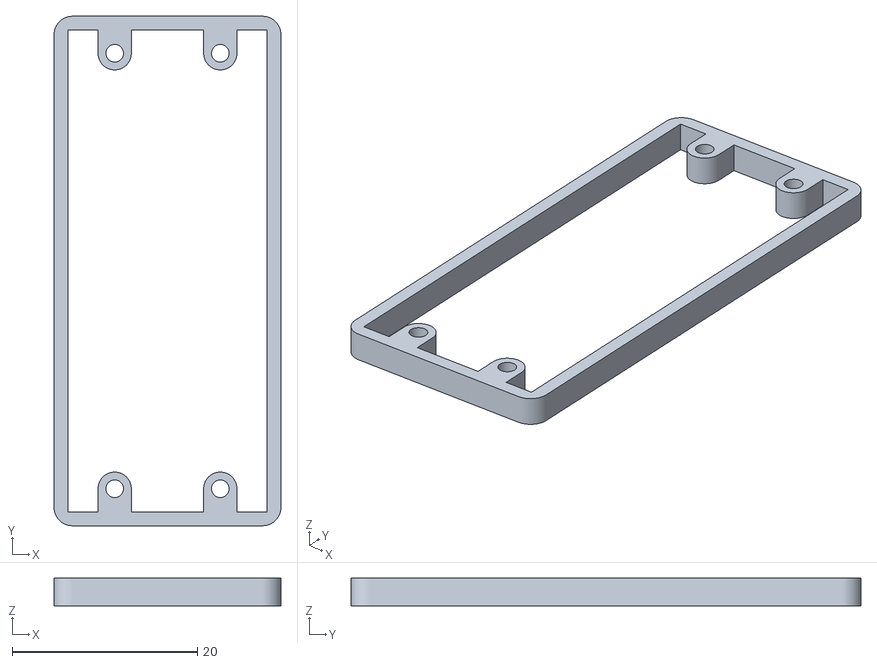
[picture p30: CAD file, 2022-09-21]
3d-printing/reference-models/Slim modular Raspberry Pi Pico Case/Case_Lower_Minimal.STL
24.5 x 55.0 x 3.00

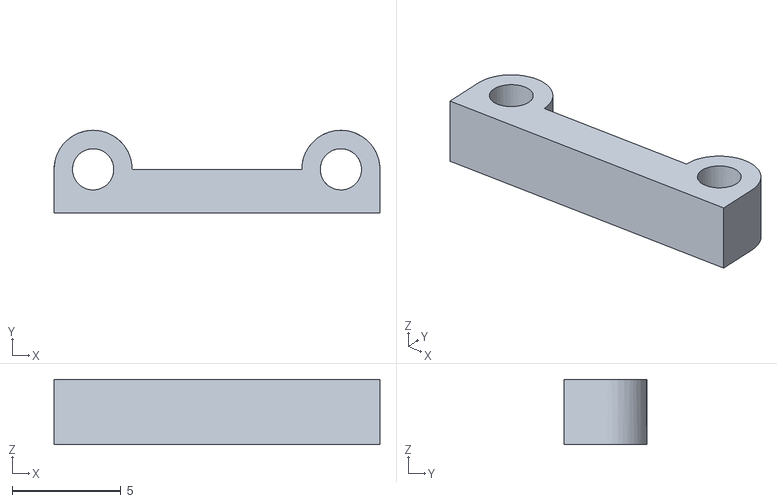
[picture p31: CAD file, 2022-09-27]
3d-printing/pico-holder.stl
15.0 x 3.80 x 3.00

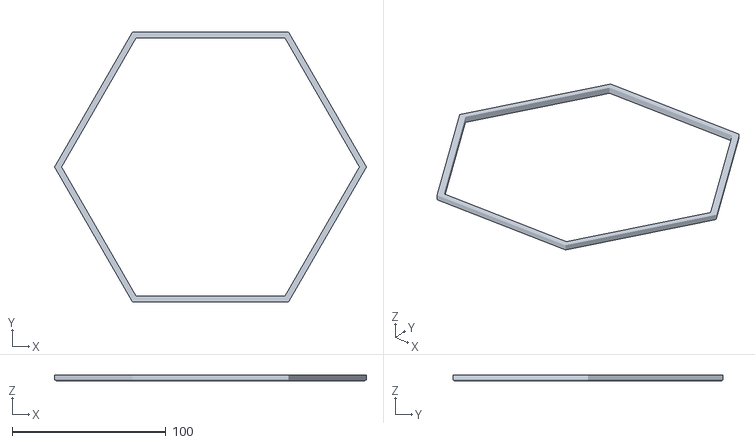
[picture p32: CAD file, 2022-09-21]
3d-printing/reference-models/Hexaleaf/Hexaleaf_Cover_Rim.stl
203.2 x 176.0 x 4.00

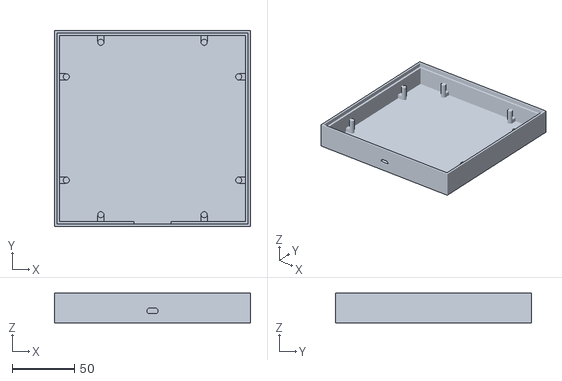
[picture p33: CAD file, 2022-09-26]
3d-printing/enclosure-with-port.stl
158.0 x 158.0 x 24.0

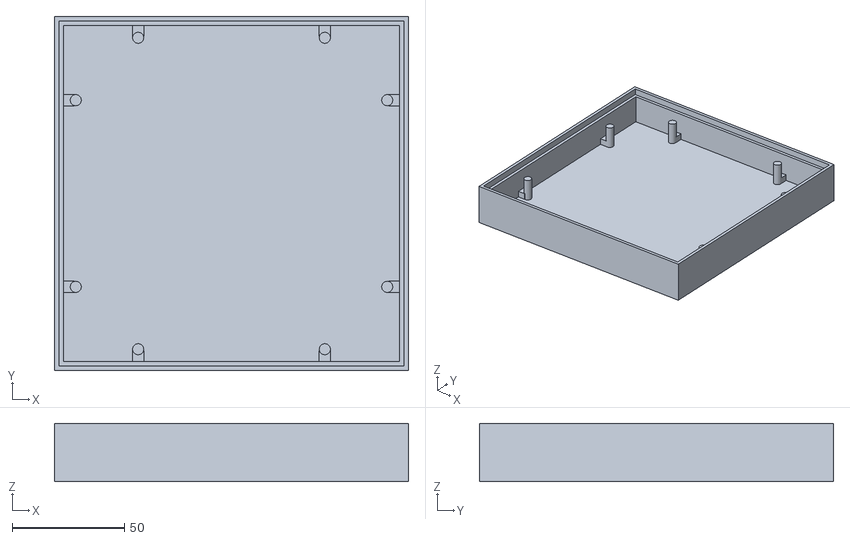
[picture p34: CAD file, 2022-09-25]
3d-printing/enclosure.stl
158.0 x 158.0 x 26.0

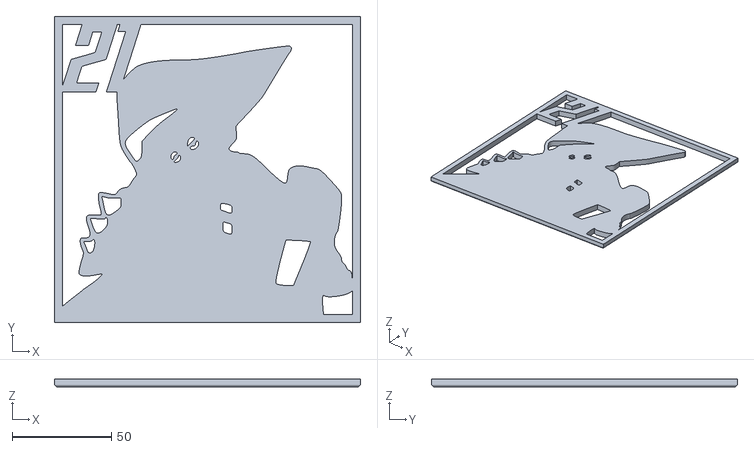
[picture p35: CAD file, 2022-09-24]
3d-printing/cover.stl
154.0 x 154.0 x 4.00

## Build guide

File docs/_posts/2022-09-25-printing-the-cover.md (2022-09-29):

---
cover-img: assets/images/cover-finished.jpg
date: 2022-09-25 07:00:00 +1200
layout: post
readtime: true
tags: [3D printing, Octoprint]
title: "Printing the cover"
---

I kicked the cover print off just after 7 am this morning. I got the slicing sorted in Cura first and then loaded the GCode into Octoprint. I was happy with the first layer and print adhesion:

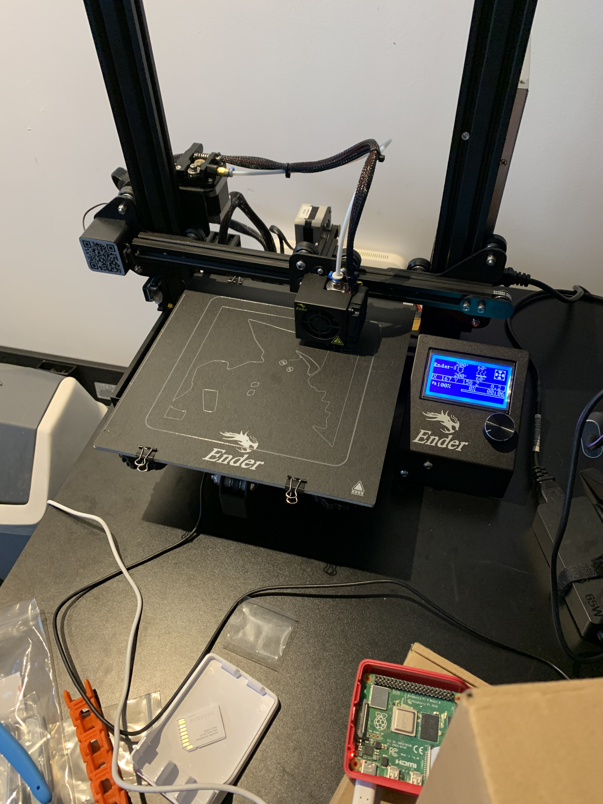
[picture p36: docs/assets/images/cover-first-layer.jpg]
First layer


I checked in on the print every now and then on my phone, to make sure nothing catastrophic was going on. After a few hours, you could start to see the infill being printed:

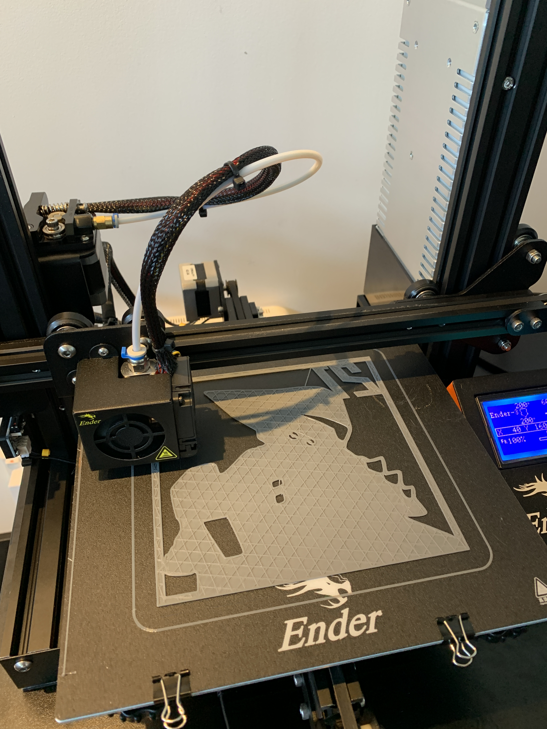
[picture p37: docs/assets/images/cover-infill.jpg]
Infill


I managed to grab a screenshot of the GCode viewer just before the last layer was finished:

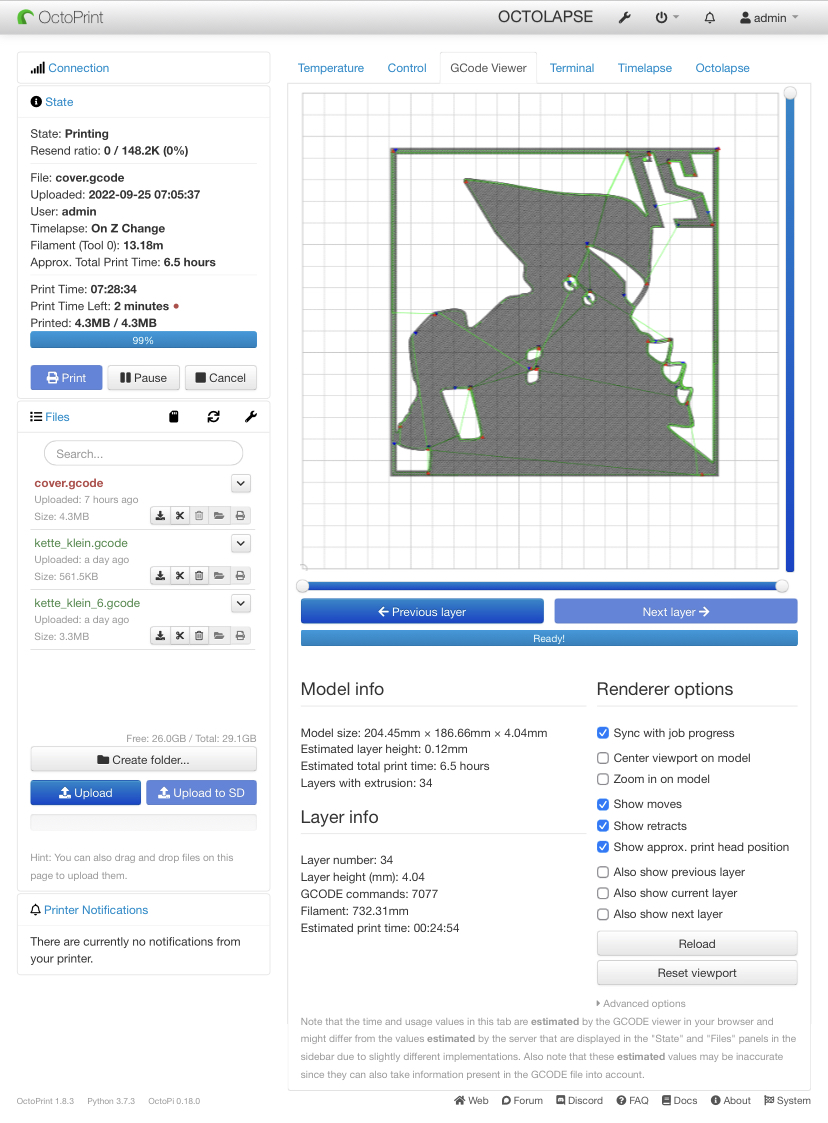
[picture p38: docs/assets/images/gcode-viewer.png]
Final layer


After 7 hours 28 minutes and 13.18 m of filament, the cover was done!

I waited a while to let the bed cool before very carefully removing the print. The print quality was extremely good and after removing some minor imperfections and stringing, this is the finished result:

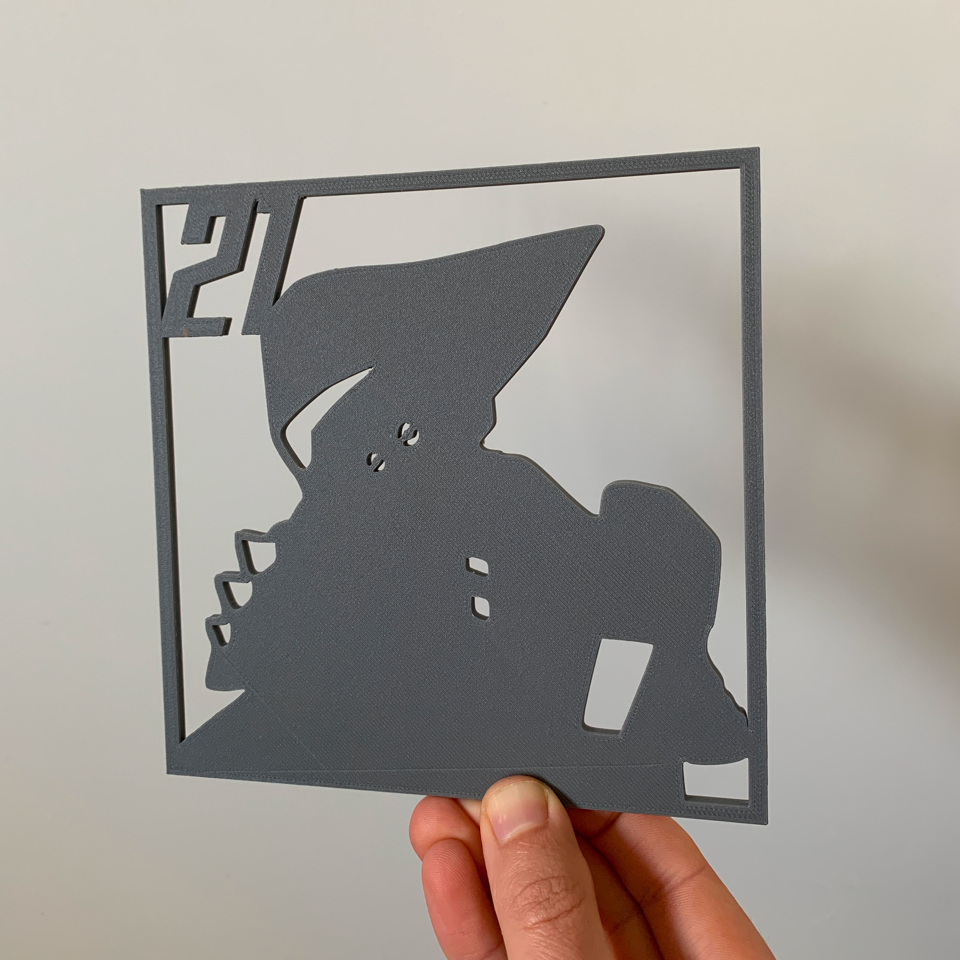
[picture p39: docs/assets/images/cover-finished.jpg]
Finished cover


I really want the finished gift to be black. I only have grey and orange filament at the moment so I went and bought some black spray paint from the local hardware store. Yet another thing to learn how to do.



Later in the evening, I spent more time trying to figure out the internals of the enclosure. There is a lot to think about and fit in so I sketched my thoughts out.

The inside of the enclosure will be laid out roughly as follows:

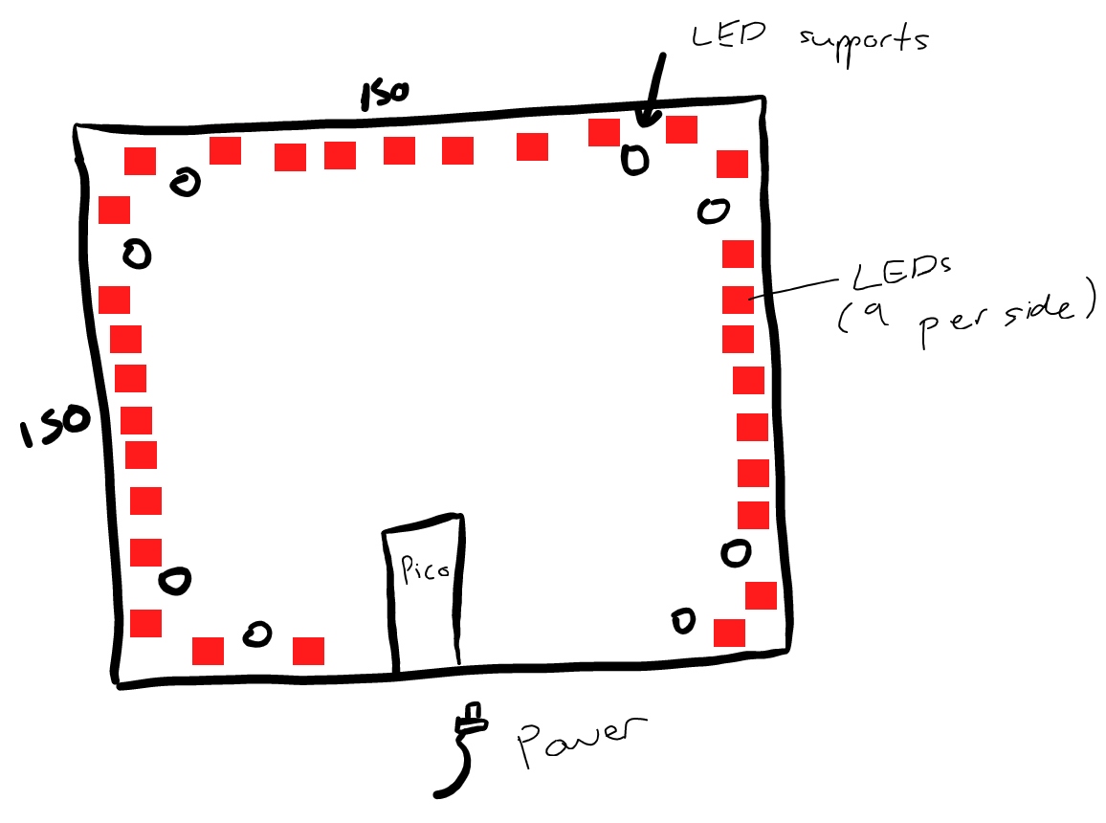
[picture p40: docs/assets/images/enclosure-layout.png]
Enclosure layout


The LED strip will be attached to the internal wall of the enclosure in a clockwise direction, starting at the Raspberry Pi Pico. There will be nine LEDs on each face except for the bottom, where there will only be three. This should not be a problem as the majority of the bottom portion of the cover is solid, meaning no light will come through anyway.

I have included two cylindrical LED strip supports on each side, similar to the Hexaleaf design:

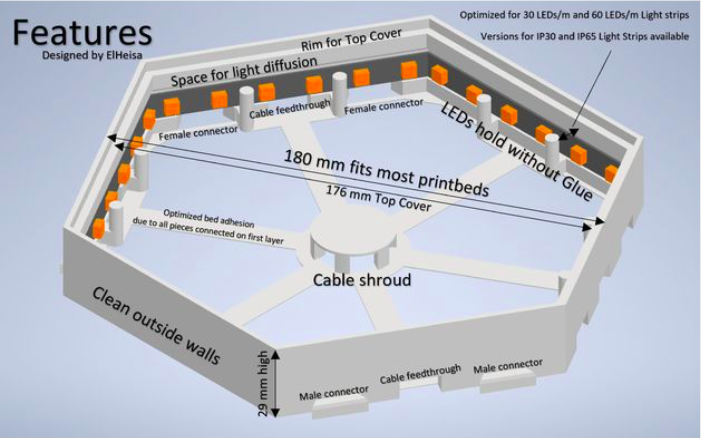
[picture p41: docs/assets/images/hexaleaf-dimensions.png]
Hexaleaf design


Cross-section where there is an LED strip support:

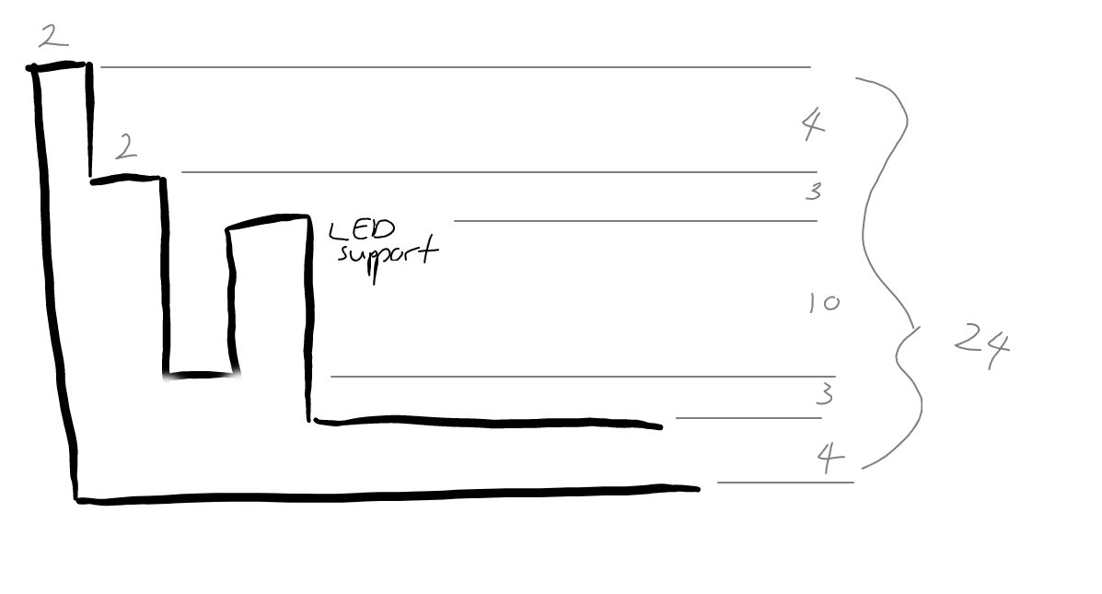
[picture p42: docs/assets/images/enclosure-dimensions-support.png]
Enclosure cross-section w/ support


Cross-section where there is no LED strip support:

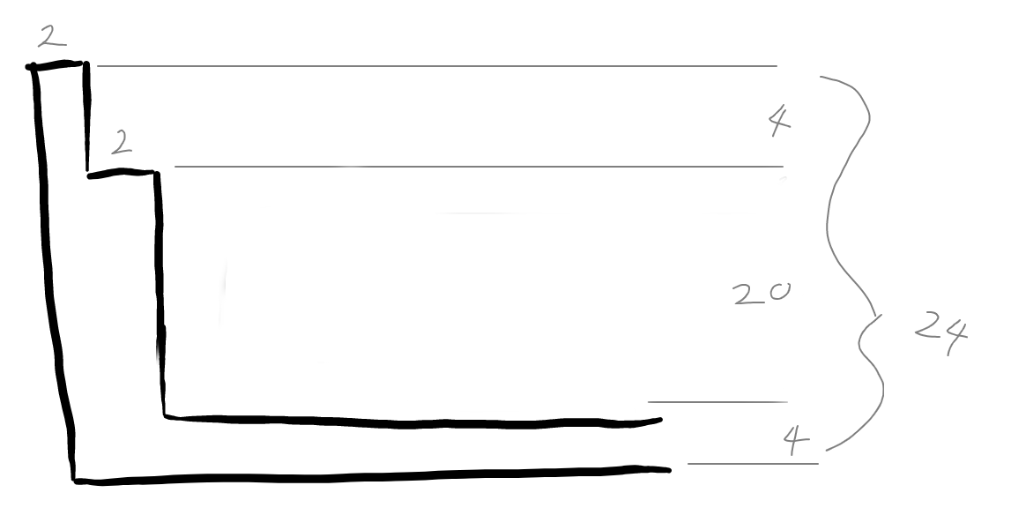
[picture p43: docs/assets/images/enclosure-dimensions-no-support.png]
Enclosure cross-section w/o support


Tomorrow I will need to try and get this modelled in Tinkercad.

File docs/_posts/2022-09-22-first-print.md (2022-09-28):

---
cover-img: "assets/images/calibration-cube-stl.jpg"
date: 2022-09-22 06:00:00 +1200
layout: post
readtime: true
tags: [3D printing, Octoprint]
title: "First print"
---

I am not counting the bed levelling print from yesterday 😉. The first "proper" thing I wanted to print is something to test how well my printer is printing. This is known as a benchmark or torture test print and the most common is Benchy:

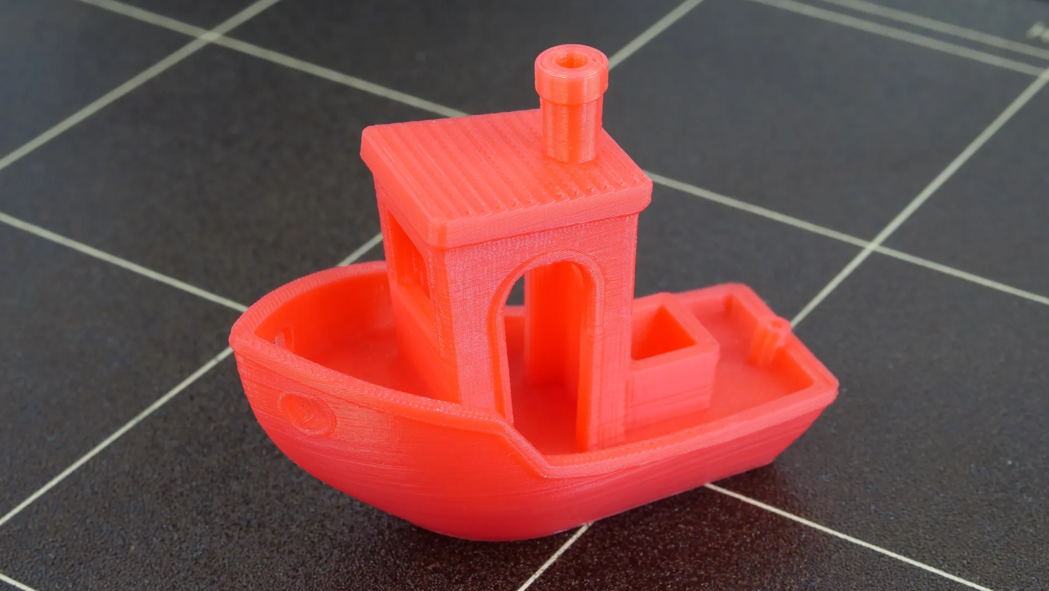
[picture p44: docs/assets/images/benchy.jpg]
Benchy


I am sure I will print one of these at some stage but because I want to make sure I can print things with good dimensional accuracy, I decided to print a calibration cube first:

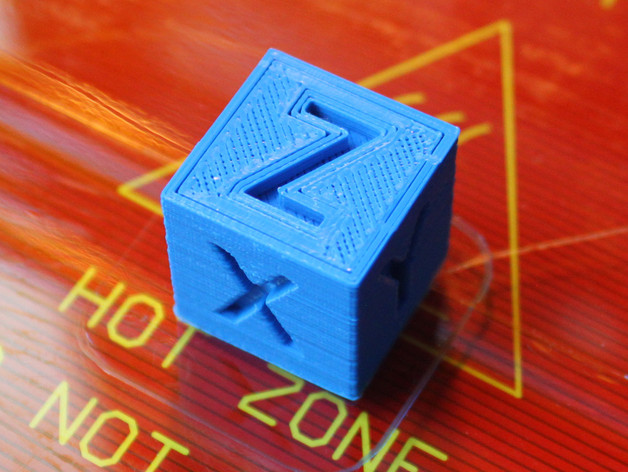
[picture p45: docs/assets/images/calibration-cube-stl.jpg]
Calibration cube


I downloaded the STL, and sliced the print in Cura:

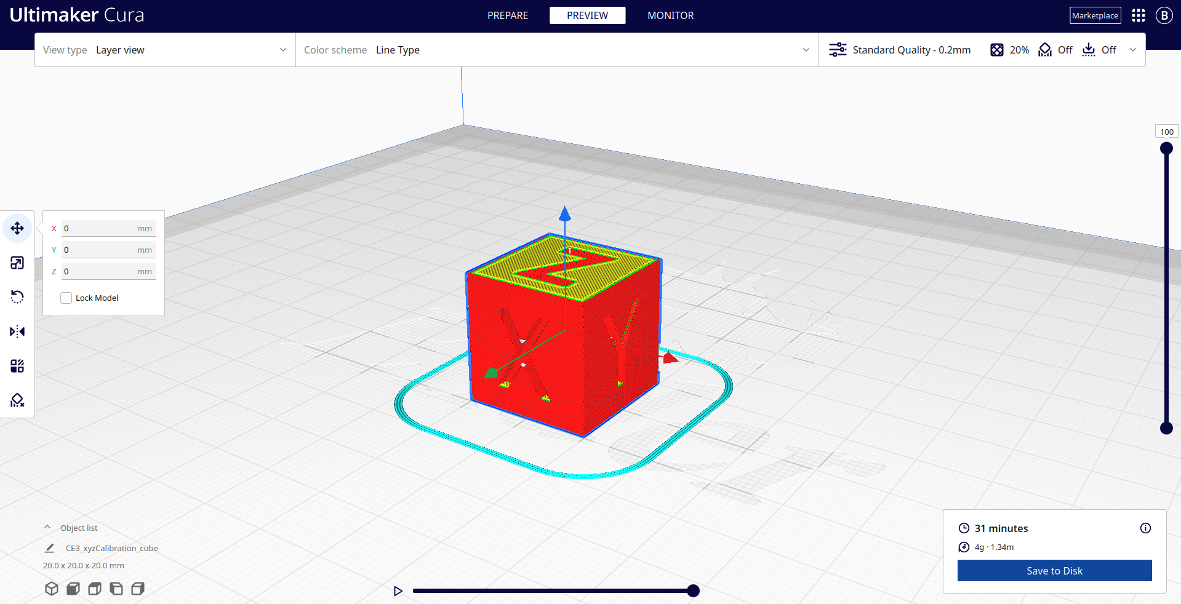
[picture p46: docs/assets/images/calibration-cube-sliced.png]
Calibration cube sliced


Once I had changed the settings to use a 30% infill and 0.1 mm layer height as suggested by the model author, I downloaded the G-code.

I hooked up my Raspberry Pi to the printer to see how Octoprint would cope. I was greeted with a lovely error message telling me that the Ender 3 firmware was not compatible with Octoprint and I would have to download a plugin to fix this (specifically the temperature readings). Once the plugin was downloaded, there was no more error message. I was then able to see the nozel and bed temperatures, as well as view the camera stream and move the print head using the controls in the Octoprint interface. Triggering the print through the interface was also possible.

Things seemed to mostly behave however, I did notice a couple of times during the print, the printer would seem to freeze. Thankfully, after a few seconds, it seemed to carry on. This is the result of the first print:

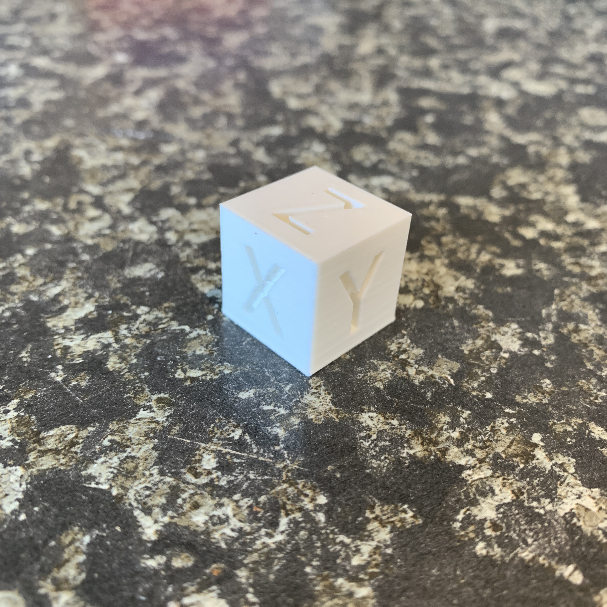
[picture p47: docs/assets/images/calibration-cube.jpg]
Finished calibration cube


I am very happy with this! There are a few issues:

* Elephant's foot at the bottom of the print
  * I suspect this is caused by the nozel being too close to the bed for the first layer
* Sharp points within the 'X' and 'Y' seem a bit messy
* Random little bulge on one of the walls
  * This may have happened during one of the random print freezes

The cube is supposed to be 200 x 200 x 200 mm. Mine was not exactly those dimensions but very, very close so I don't think I need to perform any stepper motor adjustment. The worst offending axis is definitely the 'Z' axis but I think this is because of the Elephant's footing mentioned above.

Octoprint wasn't able to create the timelapse for me. I assume this is because it's running on an old Raspberry Pi. I had to grab the photos from the Pi and create the timelapse manually. It doesn't seem as smooth as the examples I have seen so I will try and figure out what settings Octoprint uses to generate its timelapses.

After thinking about this some more, I decided to repurpose my Raspberry Pi 4 that is running Home Assistant for this project. This will allow me to use Octoprint to its full potential.

The next thing to work on is the Tinkercad model for the enclosure, as well as finishing off the cover. I may also print some printer upgrades while I am at it 😁. This video inspired me:

<iframe width="560" height="315" src="https://www.youtube.com/embed/kG_YKeJDaX8" title="YouTube video player" frameborder="0" allow="accelerometer; autoplay; clipboard-write; encrypted-media; gyroscope; picture-in-picture" allowfullscreen></iframe>

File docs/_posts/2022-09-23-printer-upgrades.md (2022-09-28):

---
cover-img: "assets/images/level-up.png"
date: 2022-09-23 06:00:00 +1200
layout: post
readtime: true
tags: [3D printing, Octoprint]
title: "Printer upgrades and timelapses"
---

I decided to spend today printing some upgrades to my printer from the video I linked at the end of yesterday's post. This will achieve a few things:

* See how well the printer is tuned
* Add some functionality and colour to my printer
* Let me experiment with different types of timelapses.

## Fan Guard

This is a guard for the fan at the front-left of the printer. I was surprised to see that no cover was included for this as filament and other debris could easily fall into the hole. This is the upgrade I am printing to address the issue:

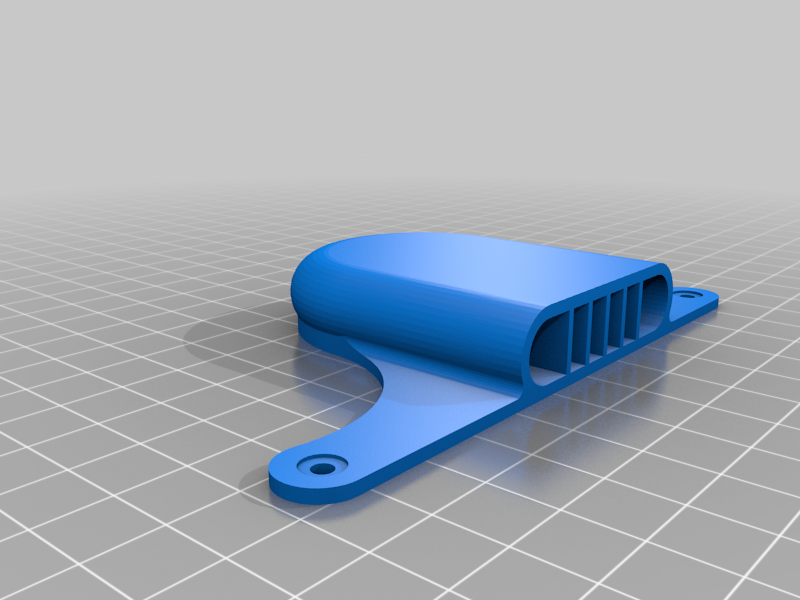
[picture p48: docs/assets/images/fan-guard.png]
Fan guard


This one turned out really nicely. Here is the timelapse:

<video muted controls width="100%">
    <source src="{{ site.baseurl }}/assets/videos/fan-guard.mp4" type="video/mp4">
</video>

## LCD Cover

The back of the LCD screen is completely exposed on stock Ender 3s. Although not technically required, I prefer to cover things like this up. This is the upgrade:

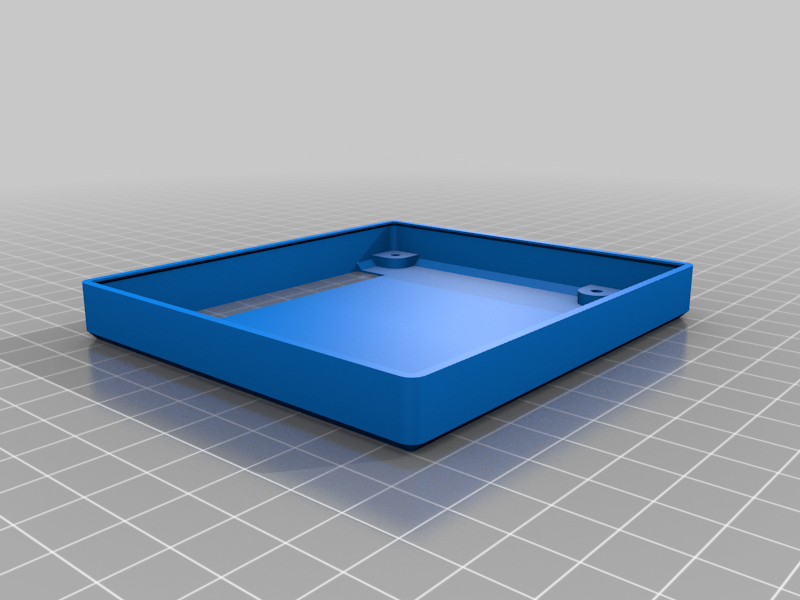
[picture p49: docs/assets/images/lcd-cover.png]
LCD cover


Here is the timelapse:

<video muted controls width="100%">
    <source src="{{ site.baseurl }}/assets/videos/lcd-cover.mp4" type="video/mp4">
</video>

## Minimalist Scraper Holder

I have been using the scraper that comes with the Ender 3 a lot to remove prints and other filament from the bed. It has been sitting on my desk until now and I often find myself looking under other tools, pieces of paper, etc. trying to find it. This little holder will let me store the scraper on the printer:

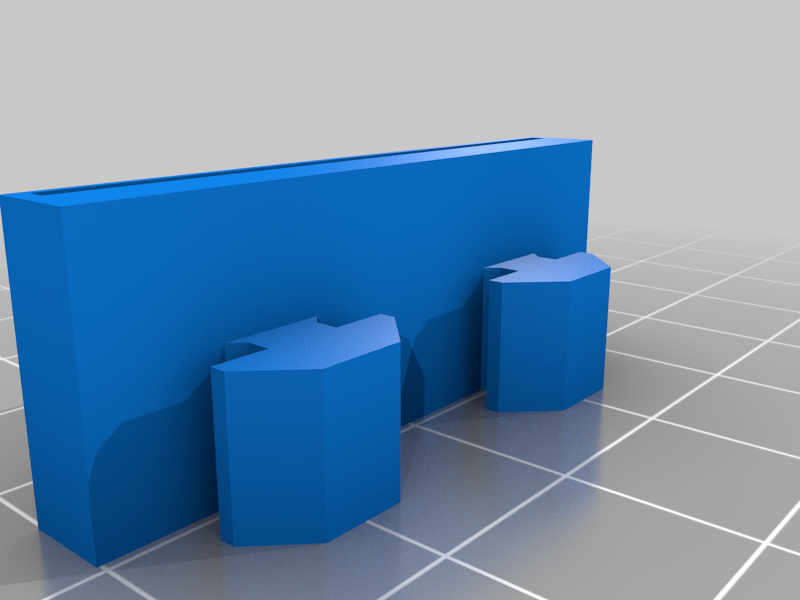
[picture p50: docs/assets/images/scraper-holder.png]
Scraper holder


Here is the timelapse:

<video muted controls width="100%">
    <source src="{{ site.baseurl }}/assets/videos/scraper-holder.mp4" type="video/mp4">
</video>

## Timelapse Comparison

The first timelapse above was created with Octoprint's default timelapse feature. This is a pretty standard timelapse (although quite jerky for my liking) and shows the print head moving around the print bed.

The second and third timelapses were created with the [Octolapse][octolapse] plugin. These are far nicer to watch in my opinion as they give the illusion the print is appearing out of thin air. This works by moving the print head to a set position at the completion of each layer, before the snapshot is taken. The downside to this is that when the print head moves away from the print, [stringing][stringing] can occur. I might be able to fix this with better retraction settings.

I think it is best if I just use a standard Octoprint timelapse for printing my brother's present, so I don't compromise on quality.

[octolapse]: https://plugins.octoprint.org/plugins/octolapse/
[stringing]: https://all3dp.com/2/3d-print-stringing-easy-ways-to-prevent-it/

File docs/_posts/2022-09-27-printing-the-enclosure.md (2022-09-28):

---
cover-img: assets/images/enclosure-cleaned.jpg
date: 2022-09-27 06:00:00 +1200
layout: post
readtime: true
tags: [3D printing, Octoprint, Pico, Raspberry Pi]
title: "Printing the enclosure"
---

Today is the day I am nervous about. The enclosure is the longest and highest thing I have printed so I am really hopeful it goes well.

I started it as early as I could so it will be done by early evening. That will give me enough time to examine, clean and test everything fits.

Here we go…

It took an hour just to print the first layer 😲.

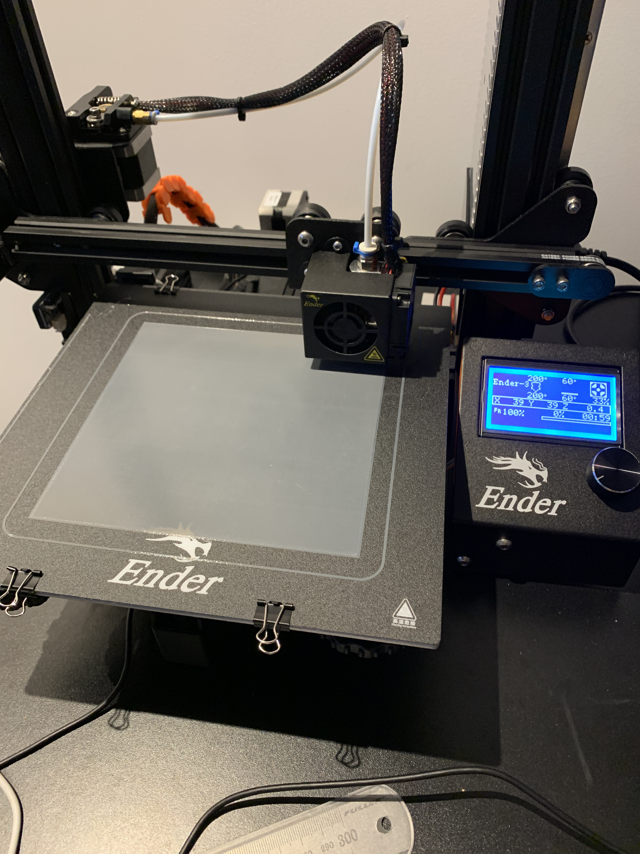
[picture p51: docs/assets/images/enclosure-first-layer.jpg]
Enclosure first layer


I will often look at the GCode viewer in Octoprint because I find it interesting. I noticed early on in the print that the print time left was 3 days:

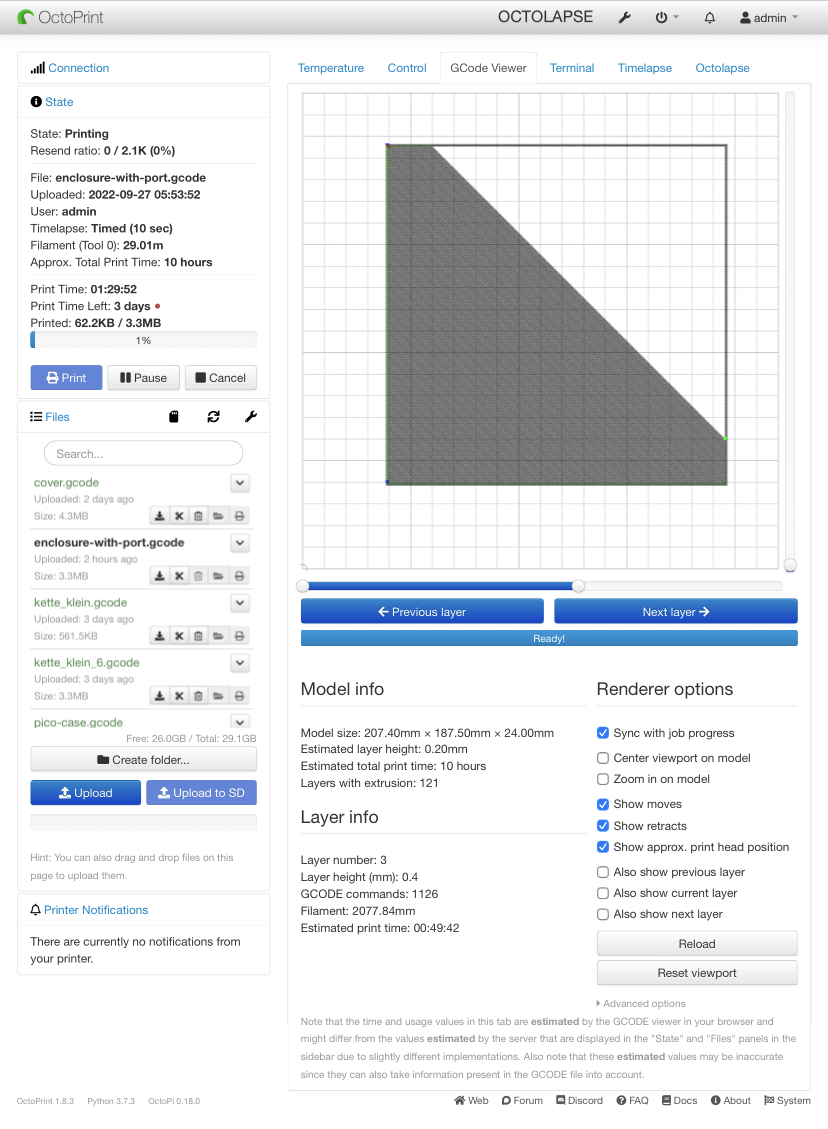
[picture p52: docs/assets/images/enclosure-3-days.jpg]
Enclosure GCode viewer


Reminds me of this 🤣.

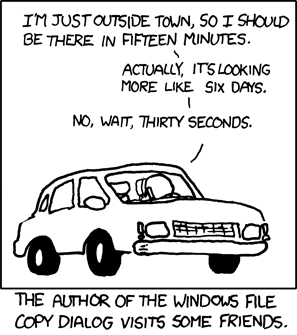
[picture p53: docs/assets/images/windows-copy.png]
Windows file copy dialog


At the 3 and a half hour mark, the infill pattern emerged:

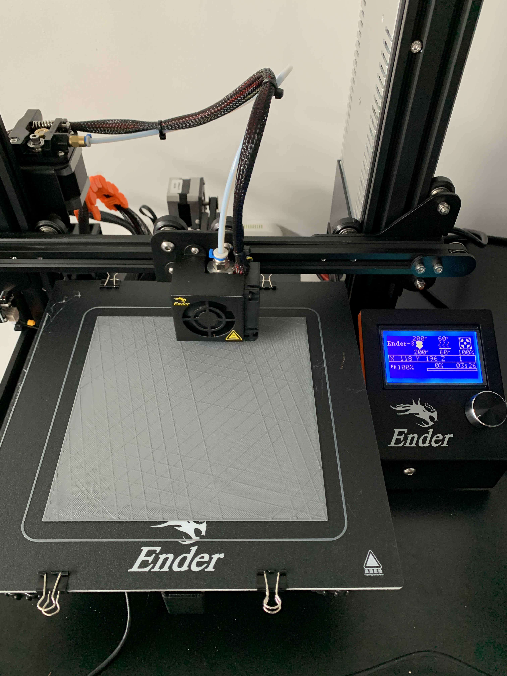
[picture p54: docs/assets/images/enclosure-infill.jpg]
Enclosure infill


Once the cylindrical holders for the LED strip started printing, I started seeing some mean stringing. I was not too concerned because this can be tidied up when the print is finished. I did keep a close eye on it though to make sure the strings would not obstruct the print nozzle:

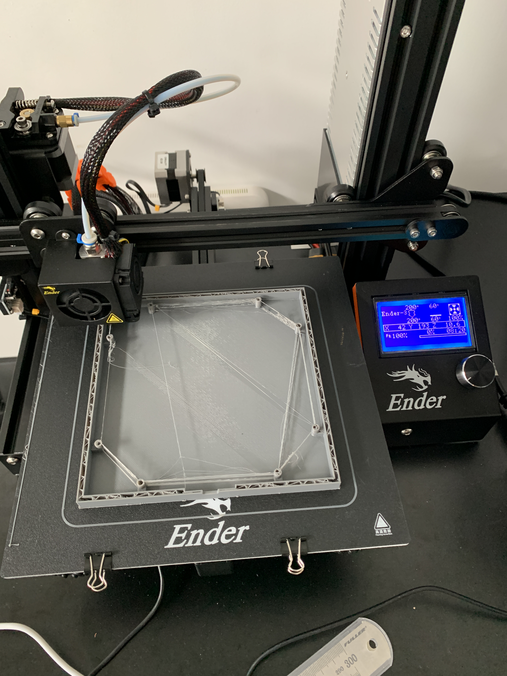
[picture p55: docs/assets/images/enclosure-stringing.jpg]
Enclosure stringing


Eventually, I could see the micro USB port appearing. I then came to a realisation that I had not accounted for the print overhang for the top of the port. You can obviously not print onto thin air so I began to plan how to handle this when the print reached that layer. I decided to just observe the first pass of filament over the port gap. To my surprise, the filament remained suspended and did not sag at all. I left the next couple of layers to print without any intervention from me. Turns out I was worried for nothing 🥹.

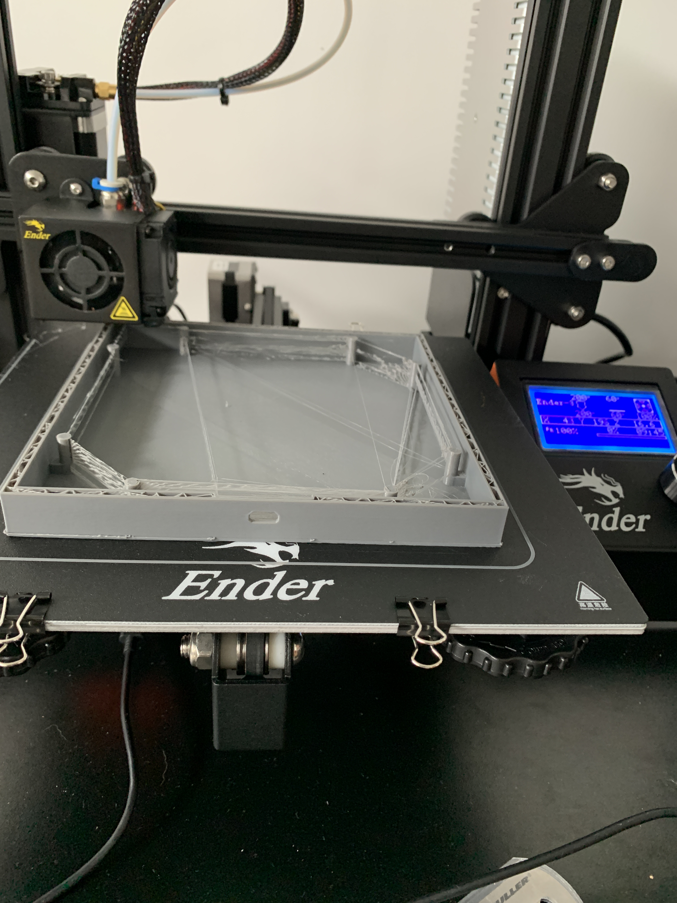
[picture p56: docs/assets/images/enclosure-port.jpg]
Micro USB port


Again, I managed to get a screenshot of the Gcode viewer just before the print completed:

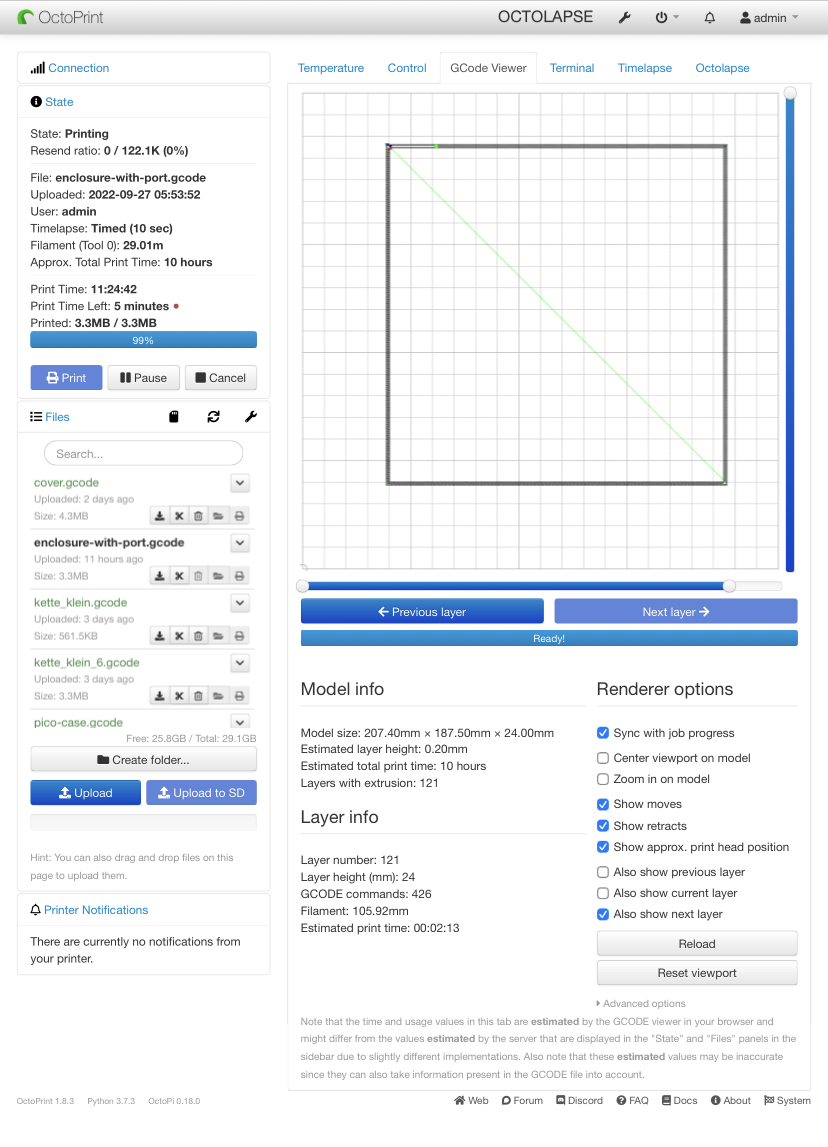
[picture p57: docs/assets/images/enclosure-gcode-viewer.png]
GCode viewer


After 11 hours 24 minutes and 29.01 m of filament, the enclosure was done!

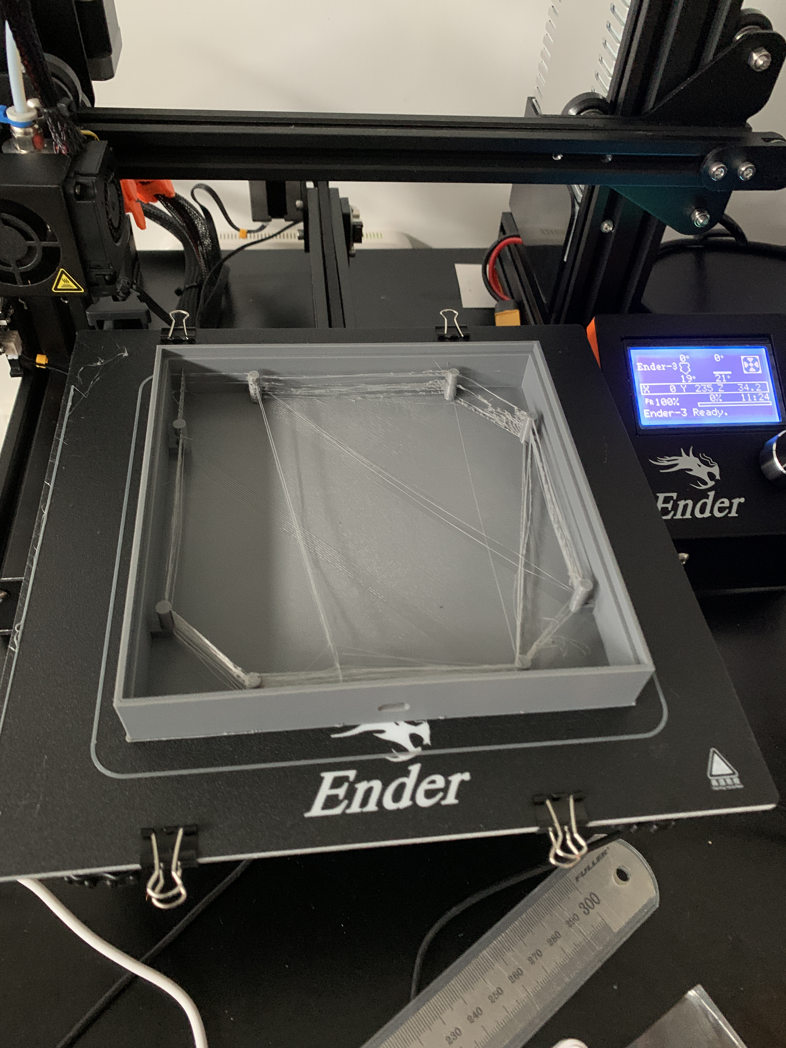
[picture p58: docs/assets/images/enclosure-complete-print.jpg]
Enclosure complete


One of the first things I did was to check if the Raspberry Pi Pico case I printed the other day fits with the port I designed on the enclosure. I realised quite quickly I had made a mistake. The person who designed the Pico case did a great job. The issue is I made the port in the enclosure the same dimensions as the one in the case. That port is not designed for a micro USB cable to pass through, but rather for the connector to plug in perfectly. You can see that clearly in this photo:

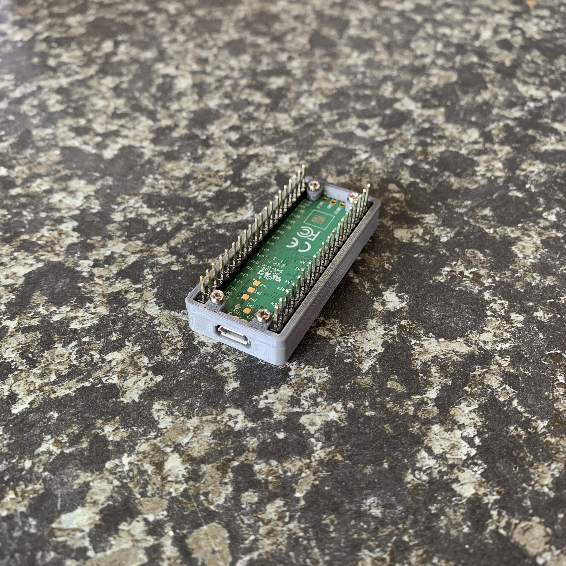
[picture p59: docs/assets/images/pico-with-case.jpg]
Pico with case


The cable plugs in nicely, but there is no clearance for the rest of the cable. Therefore, there is no way for me to plug in a cable from the outside of the enclosure. I started thinking about how to make the hole in the enclosure bigger (soldering iron, sandpaper, Drememl, etc.), but then I realised it would easier to remix the Pico case design. The goal is to remove the side of the case the port is on, so the case and Pico will sit flush with the inside of the enclosure. That should allow the Pico to be accessible from the outside.

This is the design I came up with:

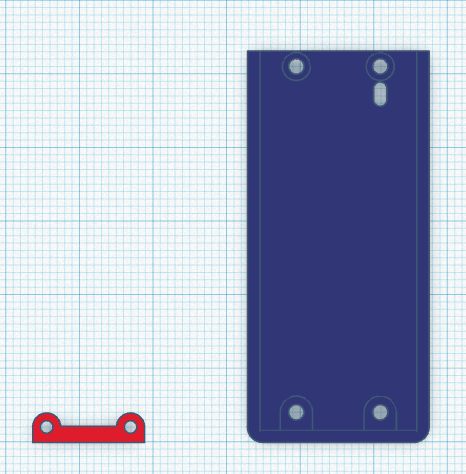
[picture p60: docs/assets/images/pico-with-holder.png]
Pico with holder


The blue part is the original case bottom with the wall with the port removed. I will print two of the red part to hold the Pico in place with screws.

## Clean Up and Fit Test

Time to move on to tidying up the enclosure and checking to see if the cover fits... After carefully cutting away the stringed sections, and the imperfections on the outside of the enclosure, this was the result:

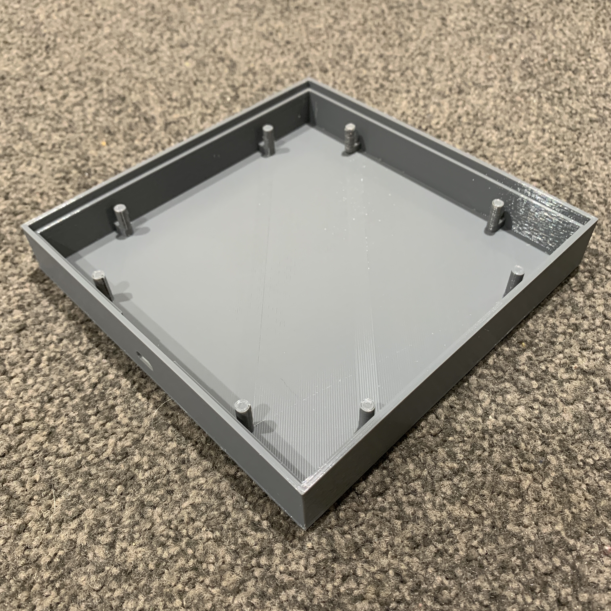
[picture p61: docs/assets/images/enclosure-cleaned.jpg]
Cleaned enclosure


Now for the moment of truth, fitting the cover into the enclosure:

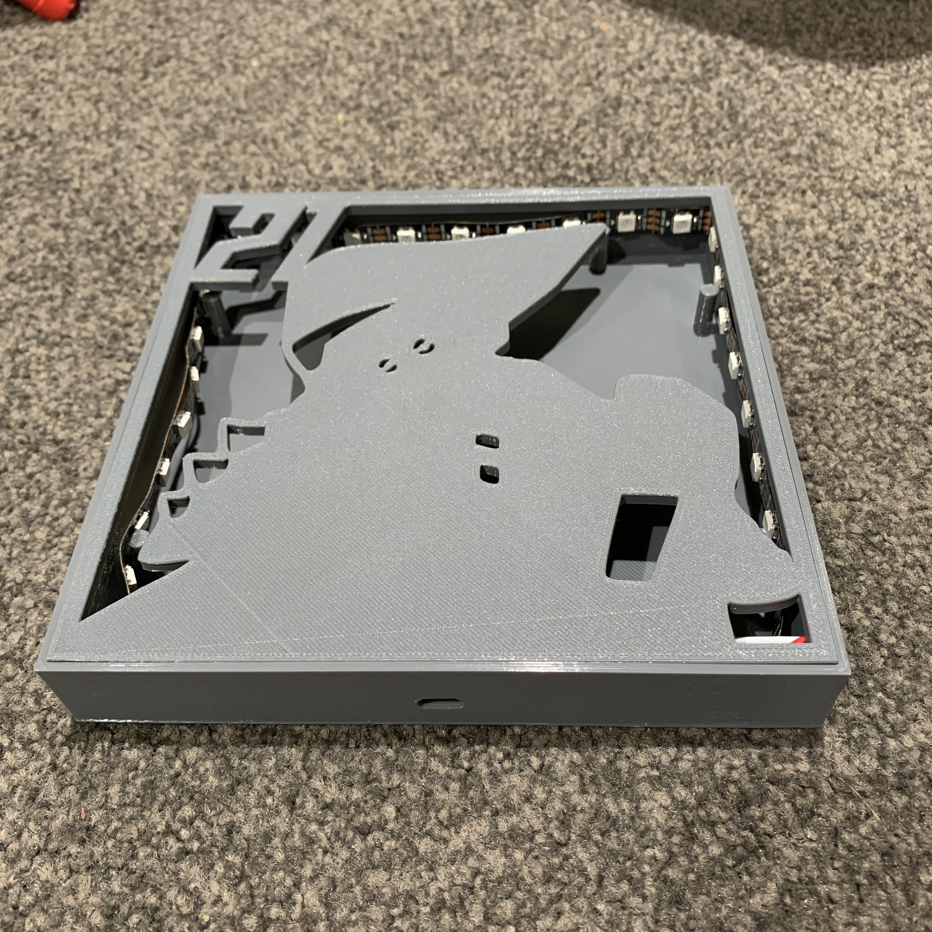
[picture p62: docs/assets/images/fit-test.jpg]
Fit test


Woohoo! 🥳 I am really pleased with how the cover fits. It is pretty snug but I am not confident it would hold in place for a long time. I wonder if the spray paint will add any thickness and make the fit any more snug. I will have to test this.

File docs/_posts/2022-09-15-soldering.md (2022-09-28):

---
cover-img: assets/images/after-soldering.png
date: 2022-09-15 06:00:00 +1200
layout: post
readtime: true
tags: [Raspberry Pi, Pico]
title: "Soldering"
---

My goal for today is to solder the header pins to the Raspberry Pi Pico. I was not sure if this was even necessary, because the Pico has castellations on in for surface mounting.

At this stage I think the Pico will need to be disconnected from the LEDs to be reprogrammed so to be on the safe side, I'll attach the header pins so the LED's can be disconnected easily.

I started by making sure I had the two strips of header pins cut to the right length:

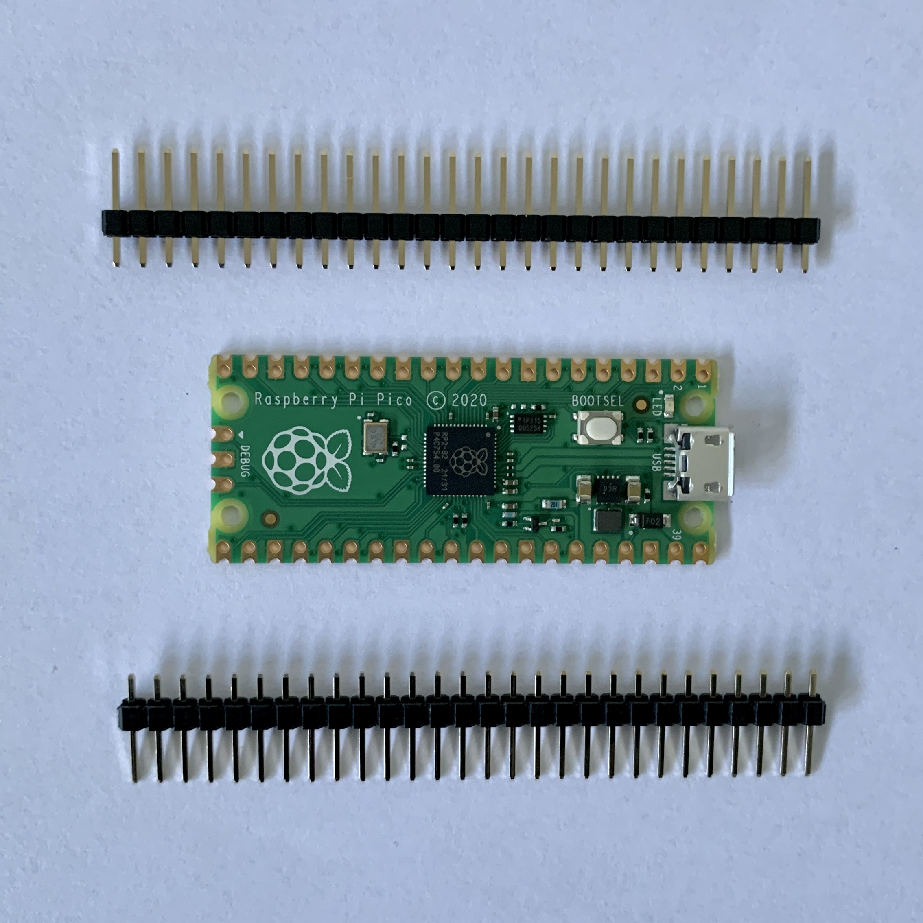
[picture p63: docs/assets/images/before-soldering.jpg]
Before soldering


Next, I put the pins in place and inserted the Pico onto a solderless breadboard to hold everything in place:

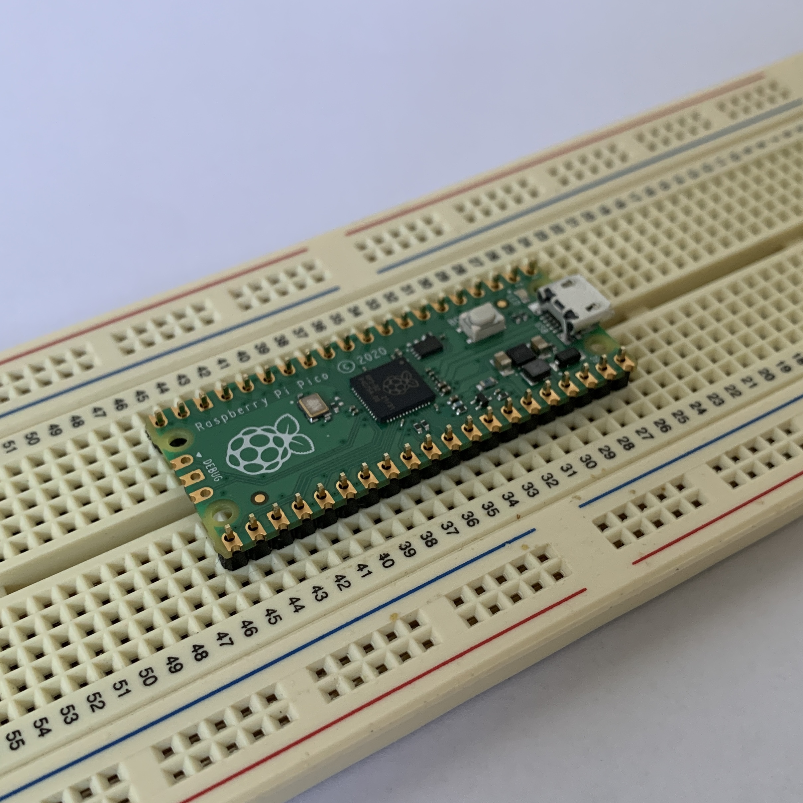
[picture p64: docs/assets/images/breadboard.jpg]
Breadboard


Once I set up my soldering station and fan for ventilation, it took around 10 mins to get all the pins soldered. Here is the finished result:

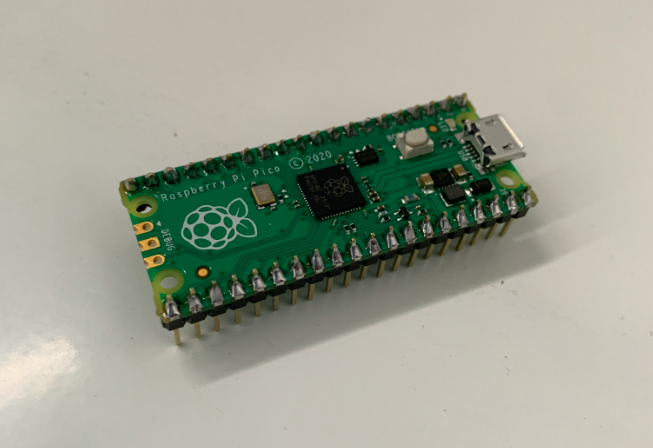
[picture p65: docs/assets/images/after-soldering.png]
After soldering


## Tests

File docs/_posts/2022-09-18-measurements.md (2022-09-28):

---
cover-img: assets/images/maths.gif
date: 2022-09-18 06:00:00 +1200
layout: post
readtime: true
tags: [Tinkercad]
title: "Measurements"
---

Oh man there were a lot of numbers to think about today... Subconciously, I knew that it would be very hard to figure out how big everything should be. There are also things in the project such as spacing between LEDS and the size of the bolts I have that cannot be easily changed. This means I am constrained in some ways with what I can do.

I started out thinking I would build a 200 x 200 x 30 mm box.

One of my main sources of inspiration for measurements and construction is the [Hexagonal Nanoleaf - Hexaleaf][hexaleaf] project on Thingiverse:

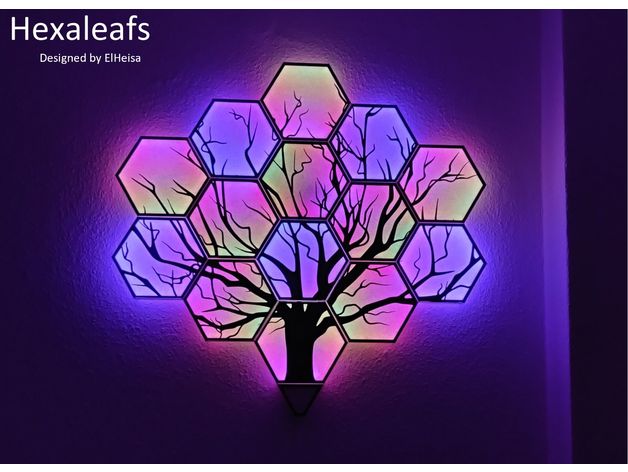
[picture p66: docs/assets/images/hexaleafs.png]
Hexaleafs


The main difference is I will be making a single, square box instead of multiple hexagons. The creator of Hexaleaf has included some of the dimensions of the project which have been very useful for my own designs:

Hexaleaf dimensions

The most important things I got from the above dimensions are the wall width of the enclosure (4 mm), the border width of the cover image (4 mm), and the height of the cover image (4 mm [3 mm + 1 mm sloped section]).:

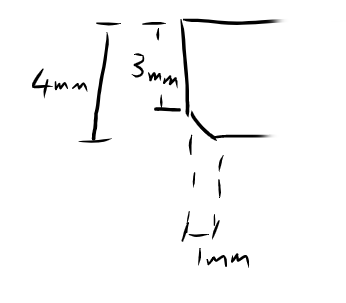
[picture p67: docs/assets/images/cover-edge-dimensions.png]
Cover edge dimensions


I was interested to see that Hexaleaf's depend on friction to hold the cover image in place, like so:

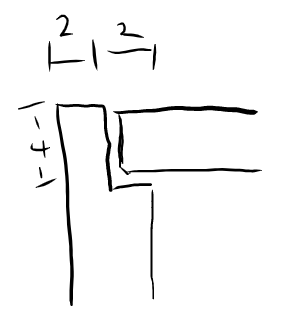
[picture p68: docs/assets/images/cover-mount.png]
Cover mount


Based on the original 200 x 200 mm dimensions I was targeting, and the 4 mm wall width of the Hexaleafs, I calculated the length of each internal wall to be 192 mm. Given the LEDs I have are spaced 16.2 mm apart, this means I can have approximately 12 LEDs per wall. This would equate to 48 LEDs in total, which I am not sure the Pico can drive.

<table>
  <tr>
    <td>
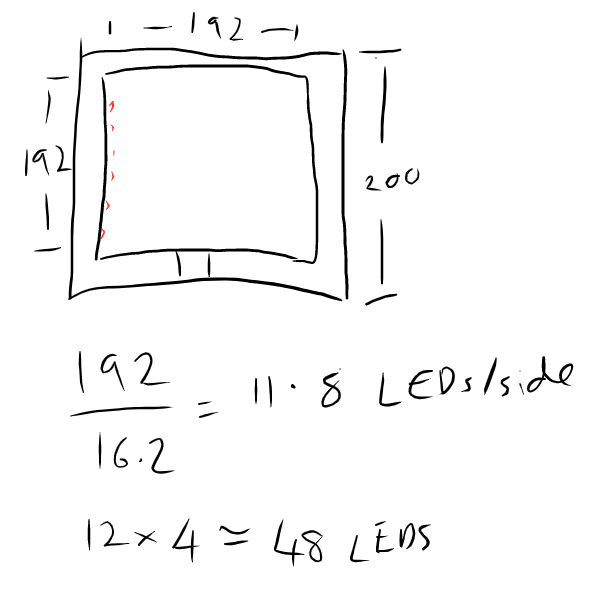
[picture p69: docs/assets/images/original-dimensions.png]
Original dimensions
      
    </td>
    <td>
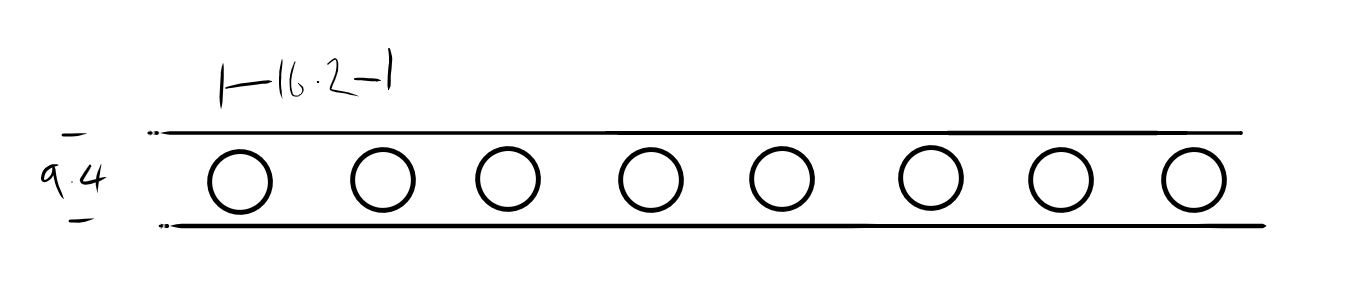
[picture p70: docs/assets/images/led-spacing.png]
LED spacing
      
    </td>
  </tr>
</table>

To be on the safe side, I will aim for 30 LEDs maximumm, 8 on the left, top, and right walls, and 6 on the bottom wall, to account for where the Pico will be mounted.

With this in mind, the ideal internal wall length will be more like 130 mm. I will include 10 mm on either side, giving a final internal wall length of 150 mm. Including the 4 mm wall width, results in a 158 x 158 mm square:

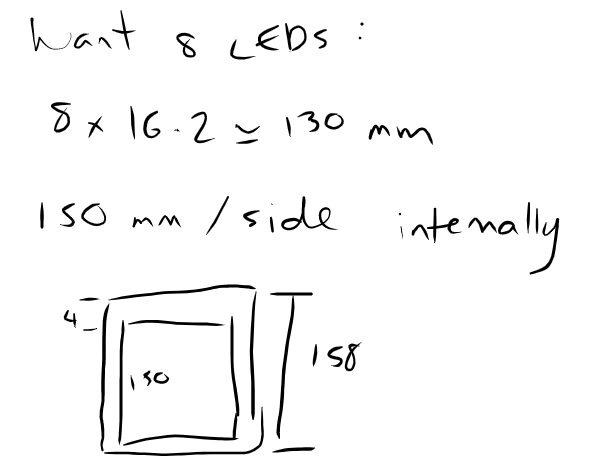
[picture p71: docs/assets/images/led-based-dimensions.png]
LED based dimensions


What all of this ends up meaning for the cover image is that it will be 154 x 154 mm:

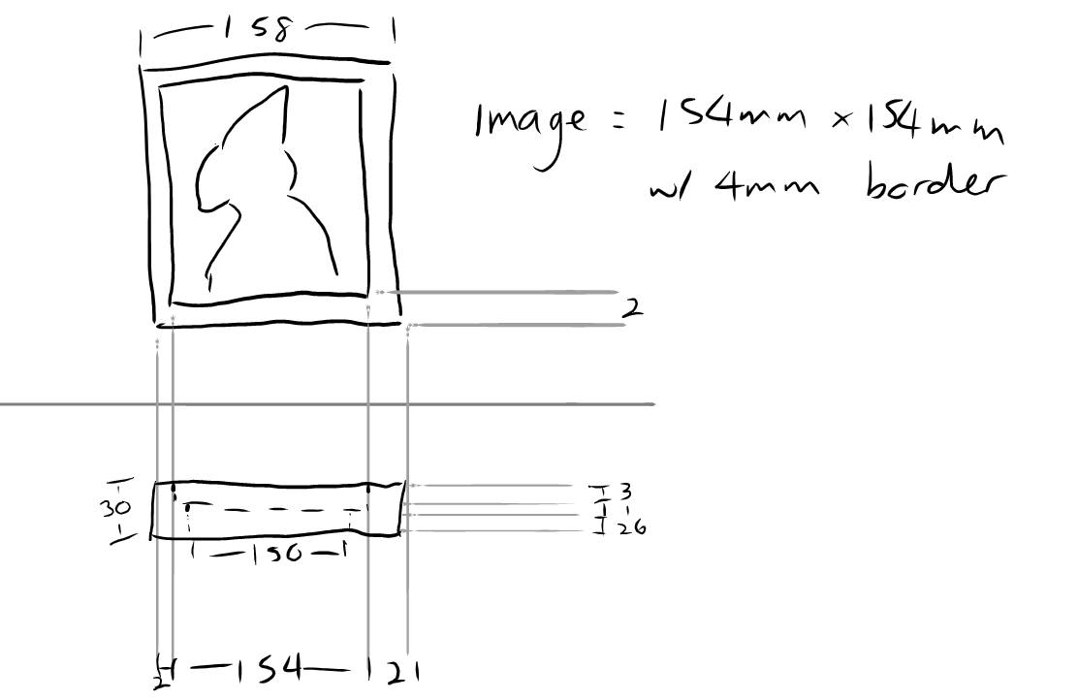
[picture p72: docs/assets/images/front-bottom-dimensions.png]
Cover dimensions


I ended up having to tweak the SVG a bit to make sure the border is 4 mm:

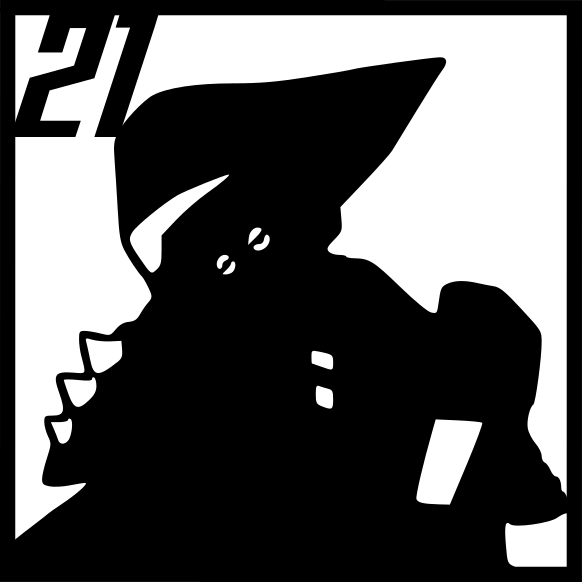
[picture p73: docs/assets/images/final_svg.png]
Cover image


That was just for the X and Y axis of the project... Let's talk about the Z axis 😅.

There are several layers to the Z axis:

* Cover image
* LED strip
* Base of the enclosure

There is also the Rasperry Pi Pico but that will sit in the middle of the enclosure and it not very thick so don't think it needs to be included here. I will add a 1 mm space between the LED strip and top/bottom of the enclosure.

Given the above:

`4 mm (cover image) + 1 mm + 9.4 mm (LED strip) + 1 mm + 4 mm (base) = 19.4 mm`

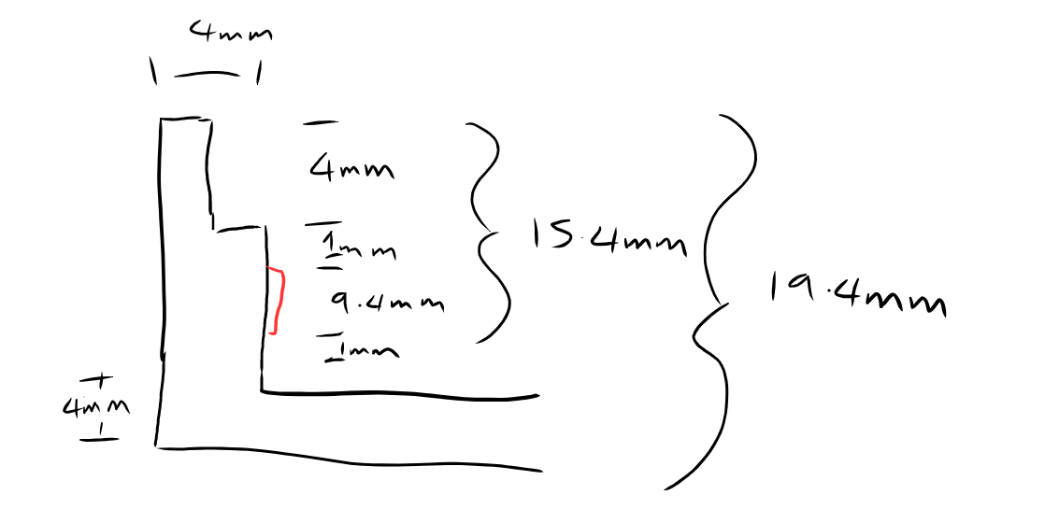
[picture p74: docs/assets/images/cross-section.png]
Cross section


## Tinkercad

I had a go at getting the SVG into Tinkercad. It was a bit of a battle because Tinkercad doesn't seem to deal with anything except paths (i.e. text and shapes don't work). Happy with the result:

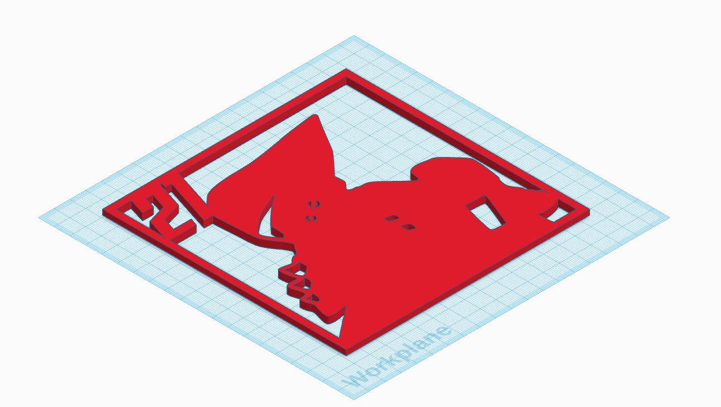
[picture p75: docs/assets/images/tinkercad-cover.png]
Tinkercad cover


[hexaleaf]: https://www.thingiverse.com/thing:5154193

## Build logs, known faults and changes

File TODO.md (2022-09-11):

# TODO

- pre-commit
- Building my 3D printer
- Designing the enclosure
- Controlling WS2812B LEDs with the Pico

## Questions

- Lights
  - How many can I control and at what brightness?
  - How do I wire them up?
  - How do I mount them? (tape vs supports)
- Enclosure
  - Do I need white filament for the backing to improve the light diffusion?
  - How do I attach the front image to the rest of the enclosure? (friction, bolts, glue)
- Front image
  - How do I keep the paper/diffuser in place?

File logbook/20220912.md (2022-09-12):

# Monday - 12/09/2022

## LEDs

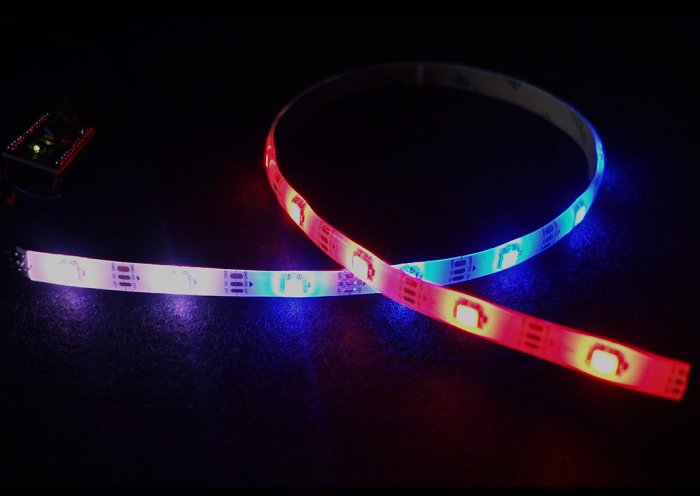
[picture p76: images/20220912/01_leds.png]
WS2812B LEDs


**Note:** These aren't actually my LEDs but show the kind I am working with.

The next relatively big unknown for me is how to control the WS2812B LED strip I have with a Raspberry Pi Pico. I have confirmed that the strip I have uses 5V for power which is a good start but I have no idea how many LEDs I can drive and at what power.

There seems to be quite a bit of discrepancy in what people are saying online but this seems like a good article to start with: [NeoPixel LEDs][leds].

[leds]: https://learn.adafruit.com/getting-started-with-raspberry-pi-pico-circuitpython/neopixel-leds

## Repository

I also created this repository today to document the journey 😁.

## Jekyll

While this was lower on my priority list, I had some spare time so decided to set up Jekyll for the static site generation for this repo.

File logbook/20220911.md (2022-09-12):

# Sunday - 11/09/2022

Today was all about getting a better idea of what the enclosure will look like. I have an idea of what I want it to look like in my head but when it comes to putting that into millimeter measurements, that a bit more challenging.

I've decided to go with a 200 mm x 200 mm square. I think 30 mm think will work but I wont know until I am actually holding something in my hand.

Dimensions

One of the other things that is bothering me is how I am going to attach the image to the rest of the encolsure. Possible options include glue, bolts and friction. I want something that is not permanent so my brother can switch out the front picture if he wants. This pretty much rules out glue. I have the least confience in friction because it relies on 3D printing with very small tolerances so the pieces fit together nicely. Bolts seemed to be the best option but I don't know how to make this work without losing some space on the image for bolt holes.

Image mounting options

The next challenge is how to mount the Raspberry Pi Pico inside the enclosre. One of the features I've decided on is to be able to plug a power cable directly into the enclosure so the Pico needs to be mounted in such a way that it's power port is accessible and does not move when something is plugged into it.

It also needs to be easily removable and detachable from the electronic wiring so it can have new software flashed to it.

I stumbled onto some nice case designs for a Pico that I think I can adapt to work well:

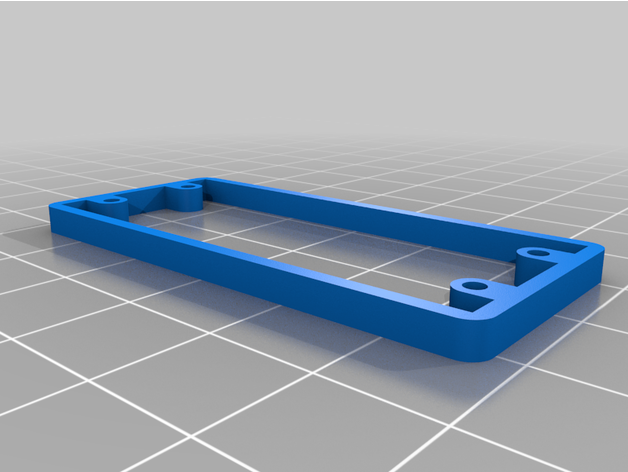
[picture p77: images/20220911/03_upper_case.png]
Upper case
| **Upper case** | 
| --- | --- |
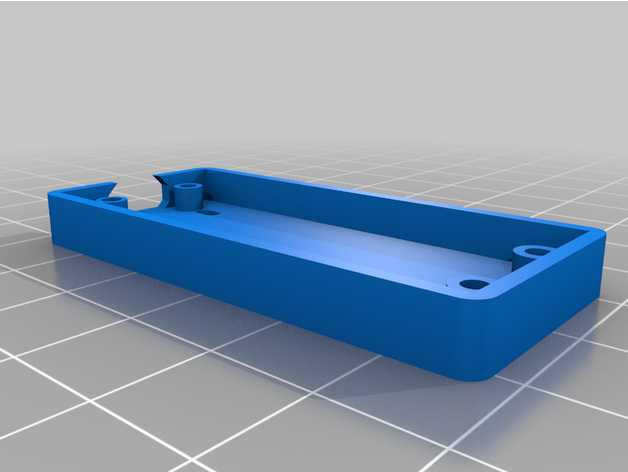
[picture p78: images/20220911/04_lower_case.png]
Lower case
| **Lower case** ||

Reference:[Slim modular Raspberry Pi Pico Case][pico-cases]

The idea is keep the mounting holes in place but stretch the **Upper case** design to the dimensions I want (200 mm x 200 mm). This should leave me with mounting holes for a Pico at one of the edges with the power port easily accessible.

The Pico is then sandwiched between the upper and lower cases to hold it in place with some bolts.

This is what the case looks like with a Pico inserted and no modifications:

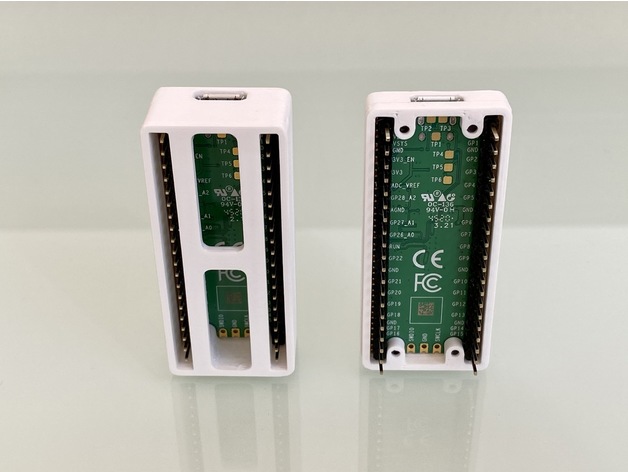
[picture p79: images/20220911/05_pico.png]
Pico


[pico-cases]: https://www.thingiverse.com/thing:4808999

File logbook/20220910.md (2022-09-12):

# Saturday - 10/09/2022

The first task in my mind was to get the front image of the lightbox designed. From what I have read, the best way to get a clean image for 3D printing is to create a SVG formatted file that I can import into it Tinkercad to generate a STL file that the 3D printer can use.

This is the image I am taking inspiration from:

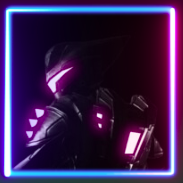
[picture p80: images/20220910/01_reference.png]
Profile picture


I want to be able to shine light through all of areas my brother has hightlighted in pink, as well as the background behind Rathet.

After spending some on Google, I was able to find the original image. I wanted to make sure the orientation and details matched as closely to the above image as possible:

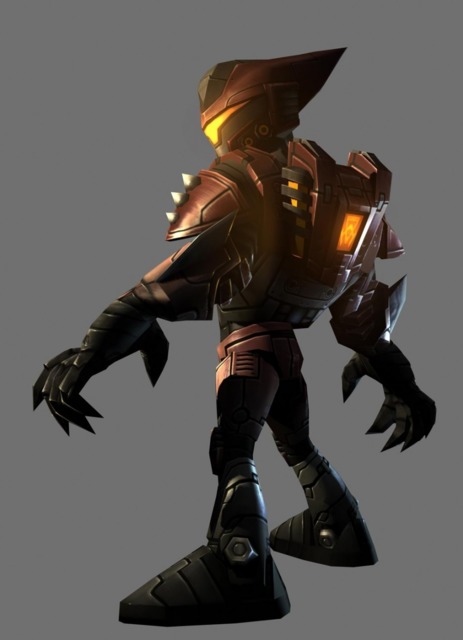
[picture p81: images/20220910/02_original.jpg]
Original image


From here, I used Gimp to make the original set of image modifications.

## Gimp

### Crop

The first step was to crop the image and remove the background colour:

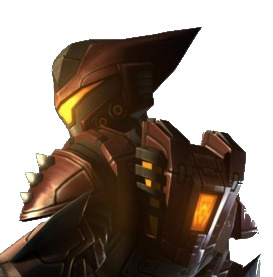
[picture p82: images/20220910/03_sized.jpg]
Sized image


### Highlight Details

I then highlighted the key areas I want light to come through:

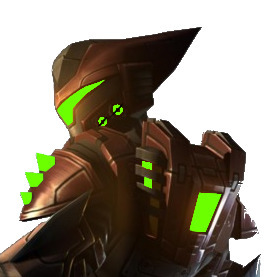
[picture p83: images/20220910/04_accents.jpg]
Accents image


I decided to highlight the rings on Ratchet's mask as well to give the light somewhere else to come through. All of the detail of his suit will be lost in the final product so I want it to have as much detail as possible. It's a slight deviation from my bother's profile picture but hopefully he won't mind 😅.

### Add Outline

I want the spikes on Ratchet's shoulder to be illuminated, as well as the entire background. I needed to make sure there was a solid outline between the two so you can see the detail of the spikes:

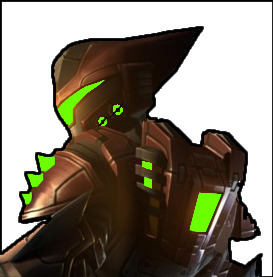
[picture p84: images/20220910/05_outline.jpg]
Outlined image


## Remove Other Details

The last step was to end up with an image showing only the areas I want the light to come through:

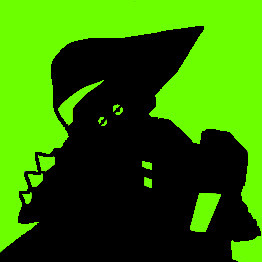
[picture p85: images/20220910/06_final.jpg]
Final image


This is a basic representation of what I hope the lightbox will look like. The green areas are where light will come through, the back is what will be 3D printed.

## Inkscape

The edges on the JPEG image above are not very clean and if I want to scale this image up, it will get blurry. I read about using a feature in Inkscape called "Bitmap tracing" to convert an image to the SVG format. SVG is a vector-based format at retains it's detail, no matter the scaling.

I wanted to add a border and "21" to the final image. This is what I ended up with:

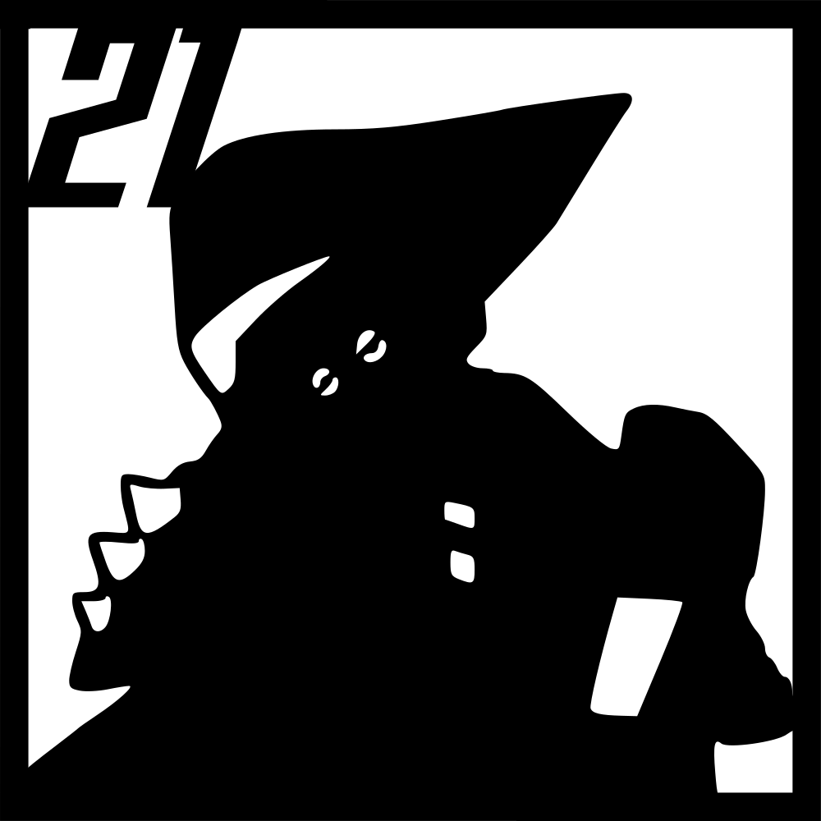
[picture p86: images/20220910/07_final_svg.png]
Final SVG


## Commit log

2022-09-12 Switch to github-pages gem
2022-09-13 Switch to beautiful-jekyll theme
2022-09-15 Add images for enclosure inspiration
2022-09-15 Add soldering post
2022-09-18 Rename soldering post
2022-09-20 Add image of soldered Pico
2022-09-20 Add sample NeoPixel code
2022-09-21 Rename pico directory
2022-09-21 Add reference STL files
    [Case_Lower_Minimal.STL, Case_Upper_No_Text.STL, Hexaleaf_Cover_Rim.stl]
2022-09-21 Add draft post for LED animations
2022-09-23 Update first print post
2022-09-24 Update cover STL image
2022-09-25 Add STL files for enclosure
    [enclosure-with-pico.stl, enclosure.stl]
2022-09-26 Add gcode for completed prints
2022-09-26 Replace STL file for enclosure
    [enclosure-with-pico.stl, enclosure-with-port.stl]
2022-09-27 Add post for 2022-09-27
    [pico-case.stl, pico-holder.stl]
2022-09-29 Add diffuser STL and GCode
    [diffuser.stl]
2022-09-29 Basic LED blink
2022-09-29 Add LED strip animations
